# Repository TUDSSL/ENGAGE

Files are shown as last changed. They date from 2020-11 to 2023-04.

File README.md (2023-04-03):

# Battery-Free Game Boy

This is the official public repository for ENGAGE: the battery-free gaming console.
    
## Project Overview

### Rationale

Battery-free devices can [make phone calls](https://dl.acm.org/doi/abs/10.1145/3090090), [facilitate machine learning](https://dl.acm.org/doi/10.1145/3411808), or even [track eyes](https://doi.org/10.1145/3241539.3241578), but immersive interactive experience without batteries has not been explored so far. In this project we focus on this ignored part of the battery-free device ecosystem. We explore how reactive and user-centric applications, _mobile gaming_ in particular, can also be battery-free.	

### The Basic Problem of Gaming without Batteries: Power Failures 

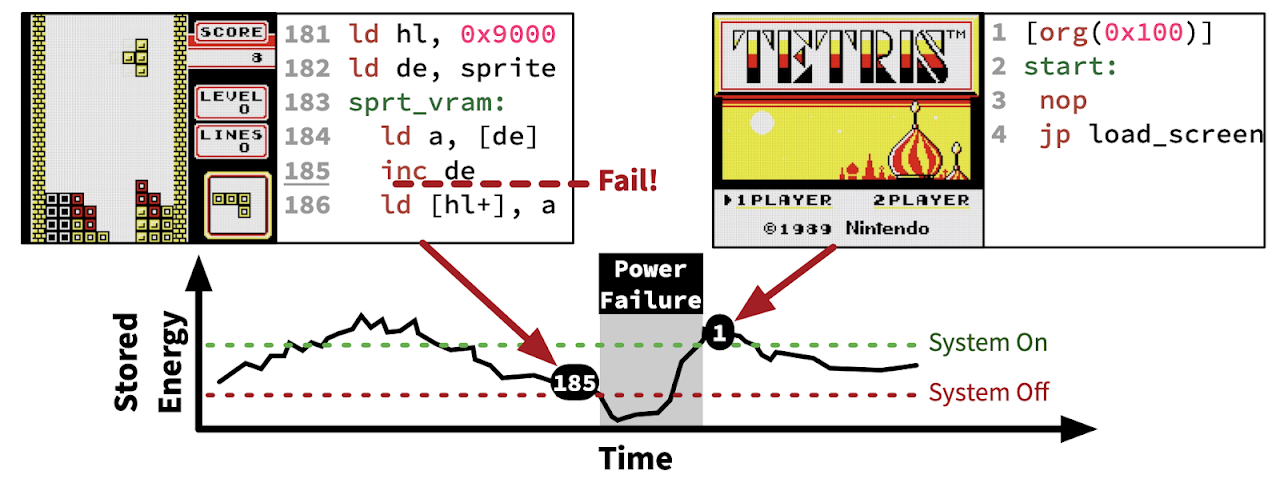
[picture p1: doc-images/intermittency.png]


Powering small embedded computer only with energy harvesting would cause frequent power failures, resulting in a constant restart of a long-running application. Let us look at the above figure which symbolically represents an execution of a [Tetris](https://en.wikipedia.org/wiki/Tetris) game on a battery-free platform powered by harvested (fluctuating) energy. Without any protection against power failures the game would play until energy is lost (i.e. at line 185) and then would restart from the loading screen. [Intermittent computing techniques](https://drops.dagstuhl.de/opus/volltexte/2017/7131/pdf/LIPIcs-SNAPL-2017-8.pdf) would protect from this unwanted behaviour: after a power failure, line 186 would be executed proceeding from the exact system state as before the power failure. This way a game state will resume at the exact frame where the play ended due to power failure (in other words, [tetromino](https://en.wikipedia.org/wiki/Tetromino) will be in the same place when the game resumes).

### System Design: Game Boy Emulation and System State Checkpointing

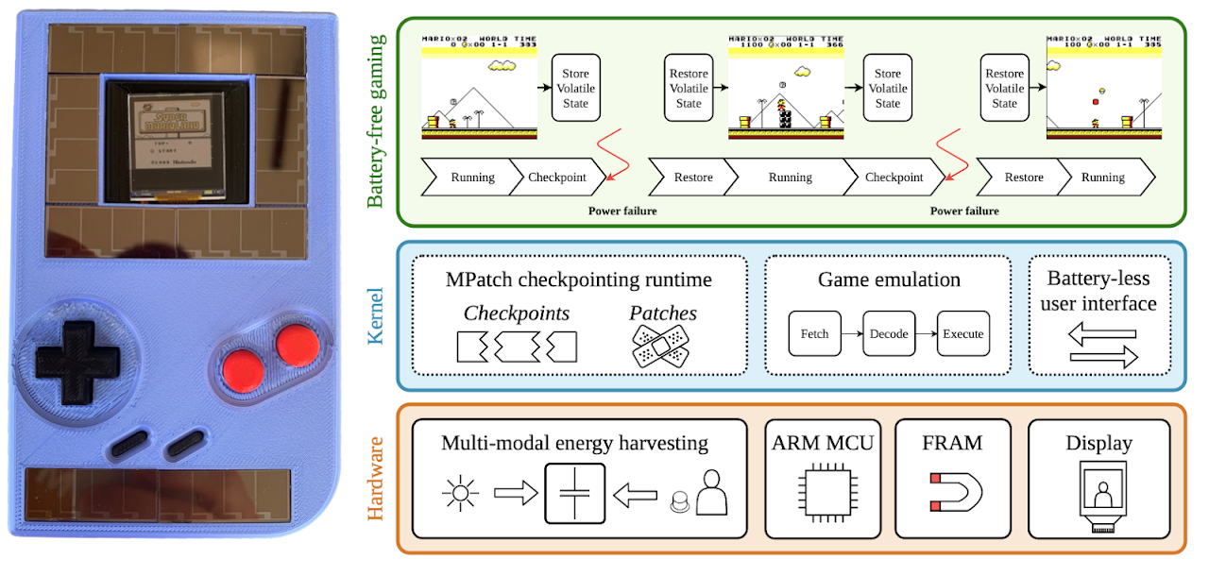
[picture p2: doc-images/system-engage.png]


We designed a Nintendo Game Boy emulator, which we call _Energy Aware Gaming (ENGAGE)_ platform, as a proof of concept that interactive systems powered by only by (intermittently-available) energy harvesting is possible. ENGAGE is build around four key components (see also figure above):

1. **Game emulation:** Use processor emulation to play (Game Boy) retro games to resemble classic [Game Boy](https://en.wikipedia.org/wiki/Game_Boy) platform feel;
1. **Kernel:** Efficiently checkpoint minimal game state to the dedicated non-volatile memory to protect from a restart after a power failure, enabling continuous game play;
1. **Energy:** Power battery-free gaming console from gaming actions (button presses) and from ambient solar energy and store this energy in a small capacitor;
1. **Hardware:** Exploit leading (but off-the-shelf and accessible to everyone) [low-power 32-bit ARM Cortex M4 microcontroller](https://ambiq.com/apollo3-blue/) and [external FRAM](https://www.fujitsu.com/global/documents/products/devices/semiconductor/fram/lineup/MB85RS4MT-DS501-00053-1v0-E.pdf) to support checkpointing system.

### Hardware

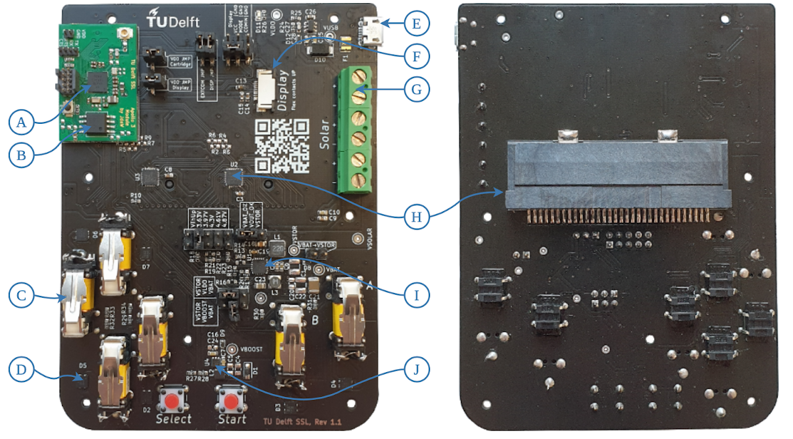
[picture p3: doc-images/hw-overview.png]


ENGAGE internal PCB is depicted on the above figure (left-hand side: front, right-hand side: back) with the main components (A) [Ambiq Apollo3 Blue ARM Cortex-M4 MCU](https://ambiq.com/apollo3-blue/), (B) [Fujitsu MB85RS4MT 512 KB FRAM](https://www.fujitsu.com/global/documents/products/devices/semiconductor/fram/lineup/MB85RS4MT-DS501-00053-1v0-E.pdf), (C) [ZF AFIG-0007 energy harvesting switch](https://nl.mouser.com/datasheet/2/833/Energy_Harvesting_Generator_US-1075748.pdf), (D) [Semiconductor Components Industries NSR1030QMUTWG low forward voltage diode bridge](https://www.onsemi.com/pub/Collateral/NSR1030QMU-D.PDF), (E) micro USB debugging port, (F) display connector, (G) solar panels connector, (H) cartridge interface, (I) [Texas Instruments BQ25570 harvester/power manager](https://www.ti.com/lit/ds/symlink/bq25570.pdf), and (J) [Texas Instruments TPS61099 boost converter](https://www.ti.com/lit/ds/symlink/tps61099.pdf).

The specific internals of ENGAGE are as follows.

**Microcontroller:** ENGAGE is based on [ARM MCU architecture](https://en.wikipedia.org/wiki/ARM_architecture), a departure from [Texas Instruments MSP430 FRAM series](https://www.ti.com/lit/an/slaa498b/slaa498b.pdf) microcontrollers typically used in [intermittent computing systems](https://drops.dagstuhl.de/opus/volltexte/2017/7131/pdf/LIPIcs-SNAPL-2017-8.pdf). Specifically, we have used [Ambiq Apollo3 Blue ARM Cortex-M4](https://ambiq.com/apollo3-blue/) (operating at a clock frequency of 96 MHz) chosen for its best-in-class energy efficiency. Apollo3 MCU (marked as (A) in the above figure) runs the Game Boy emulator and [checkpointing software](https://github.com/TUDSSL/ENGAGE/tree/master/software).

**Memory:** A fast, byte-addressable, non-volatile memory is crucial to enable saving and restoring ENGAGE state (in other words, game state) in spite of power failures. To enable this, we equipped ENGAGE with an external dedicated FRAM IC: [Fujitsu MB85RS4MT 512 KB FRAM](https://www.fujitsu.com/global/documents/products/devices/semiconductor/fram/lineup/MB85RS4MT-DS501-00053-1v0-E.pdf), marked as (B) in the above figure, connected through SPI to the MCU providing a fast (enough) and durable method of non-volatile storage for checkpoints.

**Energy Harvesting:** We extract energy from two sources: (i) button presses, using six mechanical off-the-shelf [ZF AFIG-0007 energy harvesting switches](https://nl.mouser.com/datasheet/2/833/Energy_Harvesting_Generator_US-1075748.pdf) - four switches at the D-pad and one switch per "A" and "B" button (see (C) in the above figure), and (ii) a set of [Panasonic AM-1417CA amorphous silicon solar cells](https://www.panasonic-electric-works.com/cps/rde/xbcr/pew_eu_en/ca_amorton_solar_cells_en.pdf) attached to the front of the Game Boy chassis. Solar panels are managed by [Texas Instruments BQ25570 harvester/power manager](https://www.ti.com/lit/ds/symlink/bq25570.pdf). Harvested energy is stored in a 3.3 mF capacitor.

**Cartridges:** To be able to read Game Boy game cartridges, a cartridge connector is placed on the back of the ENGAGE platform PCB (marked as (H) in the above figure). The cartridge interfaces with the MCU using [Semtech SX1503 I/O expanders](https://www.mouser.com/datasheet/2/761/sx150x-1283306.pdf). This extender translates the 3V system voltage to 5V logic required by the cartridge.

**Display:** It was difficult to source a large display that had reasonable power requirements, a decent refresh rate, and minimal external driving circuitry. We quickly discarded the use of electronic ink displays because of its slow refresh rate and complex driving circuitry. Instead we use a 26.02 × 27.82 mm [Japan Display LPM013M126A LCD](https://www.j-display.com/product/pdf/Datasheet/4LPM013M126A_specification_Ver02.pdf). The display is is smaller than the original Game Boy screen (47 × 43 mm) but has a better resolution of 176 × 176 pixels compared to original 160 × 144 pixel matrix.

### Checkpointing

The core software component of ENGAGE is differential checkpointing library called _MPatch_ located in [software/libs/mpatch](https://github.com/TUDSSL/ENGAGE/blob/master/software/libs/mpatch) folder of this repository. Further description of MPatch is provided in a separate [document](https://github.com/TUDSSL/ENGAGE/blob/master/software/libs/mpatch/README.md).

## Getting Started

This repository contains everything required to build your own Battery-Free Game Boy. Below we describe how to build your own ENGAGE hardware and software.

### Building the Hardware

Hardware-related sources are stored in the following folders.

 - [/enclosure](https://github.com/TUDSSL/ENGAGE/tree/master/enclosure): Complete set of [3D STL files](https://en.wikipedia.org/wiki/STL_%28file_format%29) of the complete ENGAGE enclosure (front, back, buttons, D-pad, LCD holder)
 - [/hardware/main-board](https://github.com/TUDSSL/ENGAGE/tree/master/hardware/main-board): Main ENGAGE board [KiCad](https://kicad.org/) files. Specifically, the folder contains `.gbr` Gerber output files for manufacturing, `.drl` drill file for manufacturing, schematics of the PCB in `.pdf` format, `.csv` file with bill of materials and the KiCad project files `.kicad_pcb`, `.pro` and `.sch`.
 - [/hardware/apollo-3-module](https://github.com/TUDSSL/ENGAGE/tree/master/hardware/apollo-3-module): As above, but for the de-attachable board with the MCU and FRAM (see above figure - component (A) and (B))
 
 Enclosure can be printed using your favorite 3D printer or you can send all [/enclosure](https://github.com/TUDSSL/ENGAGE/tree/master/enclosure) files to one of online-available 3D printing services. As for the PCBs, you can either assemble everything yourself or send all [/hardware](https://github.com/TUDSSL/ENGAGE/tree/master/hardware/) files to many online-available PCB assembly companies for production. 

### Building the Software

Software-related sources are stored in the following folders.

- [/software/apps](https://github.com/TUDSSL/ENGAGE/tree/master/software/apps): Applications' source code folder containing three applications:
    - [emulator](https://github.com/TUDSSL/ENGAGE/tree/master/software/apps/emulator): main application of ENGAGE emulator, which can be also used to reproduce [results of the paper](#How-to-Cite-This-Work);
    - [checkpoint](https://github.com/TUDSSL/ENGAGE/tree/master/software/apps/checkpoint): application to test the performance of checkpointing mechanism;
    - [memtracker](https://github.com/TUDSSL/ENGAGE/tree/master/software/apps/memtracker): application to test the performance of memory use tracking mechanism;
- [/software/config](https://github.com/TUDSSL/ENGAGE/tree/master/software/config): Various configuration files.
- [/software/external](https://github.com/TUDSSL/ENGAGE/tree/master/software/external): External dependencies to the project, such as MCU SDK.
- [/software/libs](https://github.com/TUDSSL/ENGAGE/tree/master/software/libs): Set of core libraries handling I/O (that is [console buttons](https://github.com/TUDSSL/ENGAGE/tree/master/software/libs/buttons), [game cartridge](https://github.com/TUDSSL/ENGAGE/tree/master/software/libs/cartridge), [console display](https://github.com/TUDSSL/ENGAGE/tree/master/software/libs/display), [Game Boy emulator](https://github.com/TUDSSL/ENGAGE/tree/master/software/libs/emulator), [FRAM access](https://github.com/TUDSSL/ENGAGE/tree/master/software/libs/fram)) and checkpointing (that is [just-in-time checkpoint](https://github.com/TUDSSL/ENGAGE/tree/master/software/libs/jit), [memory state tracker](https://github.com/TUDSSL/ENGAGE/tree/master/software/libs/memtracker), and [MPatch checkpointing](https://github.com/TUDSSL/ENGAGE/tree/master/software/libs/mpatch)).
- [/software/platforms](https://github.com/TUDSSL/ENGAGE/tree/master/software/platforms): GPIO pin mappings.
- [/software/scripts](https://github.com/TUDSSL/ENGAGE/tree/master/software/scripts): Scripts pertaining to the build process.

#### Note on the Game Boy Emulator

We do not provide the copy of the Game Boy emulator in this repository. Our build system (using [/software/scripts](https://github.com/TUDSSL/ENGAGE/tree/master/software/scripts)) automatically downloads and patches (applying optimizations and improvements) an external, not written by us, Game Boy emulator. Specifically, we have used [Game Boy emulator](https://mikrocontroller.bplaced.net/wordpress/?page_id=1290) for [STM32F746 Discovery board](https://www.st.com/en/evaluation-tools/32f746gdiscovery.html) written by [Uwe Becker](https://mikrocontroller.bplaced.net/wordpress/?page_id=8).

#### Build Process

After cloning this repository to your local computer the following instructions can be used to generate the ENGAGE binaries. From the project directory execute the following.

```bash
$ cd software/build
$ cmake ..
$ make install

```

Then using your favorite debugger (we have used one of [SEGGER J-Link debug probes](https://www.segger.com/products/debug-probes/j-link/models/model-overview/) for this project) the ENGAGE binaries (stored in the [/software/bin](https://github.com/TUDSSL/ENGAGE/tree/master/software/bin) folder) can be uploaded to the MCU using a debugger whilst powering the platform using USB. The main binary is called `emulator` whilst the others provide a means to reproduce the results obtained in the [paper](#How-to-Cite-This-Work). After this step a [game cartridge can be loaded](#Load-Game-Cartridge).

#### Last Tested Software Versions

This software was build successfully using the following software versions.

- [CMake](https://cmake.org/download/) version 3.18.4
- [arm-none-eabi-gcc](https://gcc.gnu.org/) version 10.2.0
- [arm-none-eabi-newlib](https://www.sourceware.org/newlib/) version 3.3.0
- [arm-none-eabi-binutils](https://www.gnu.org/software/binutils/) version 2.35

## How to Operate ENGAGE

There are two important operations when using ENGAGE that are not related to normal gaming: **loading game cartridge** and **system reset**, both described below.

### Load Game Cartridge

After programming the [emulator binary](https://github.com/TUDSSL/ENGAGE/tree/master/software/bin) to ENGAGE, a Game Boy cartridge with your favorite game needs to be loaded to ENGAGE. To load a cartridge, first put the physical cartridge in the cartridge slot (at the back of ENGAGE) and then hold down **Start** and **A** buttons on ENGAGE while powering ENGAGE through the USB port. You can let go **Start** and **A** buttons after a few seconds. When loading of the cartridge has completed the game will start. Note that there is currently [no progress indication](https://github.com/TUDSSL/ENGAGE/issues/4) of this operation on the screen of ENGAGE. Remember that the process can take five minutes (or more) for large cartridges! After a cartridge has been loaded it can be removed from the device.

### System Reset

Due to the unique nature of ENGAGE's state resuming after power failure, resetting ENGAGE requires a unique key combination (unlike the original Game Boy that you could turn off and on again easily). This reset is performed by holding **Start** and **Select** buttons while powering ENGAGE through an USB port. Please note that this reset operation does *not* require you to reload the game cartridge.

## Frequently Asked Questions

- **When the energy source is changed from solar to button-mashing, how long is ENGAGE temporarily off?**

We actually harvest from both energy sources at the same time! We developed a circuit that manages this internally. However, this still means that the user will experience interruptions of play, that can vary between sub-second (in extreme well outdoor light conditions) to many seconds (on a gloomy day, indoors). While the button presses generate extra energy to sustain game play, most of the energy is still generated by solar panels. More discussion on this can be found in our [research paper](#How-to-Cite-This-Work). 

- **How do the buttons generate power?**

The buttons generate power by moving a small but powerful magnet inside a tightly wound wire coil. The change in the magnetic field generates power. When you press the button (and when you release) it moves the magnet through the coil, this energy is then siphoned into a capacitor for immediate use by the ENGAGE hardware to support all activities. Because of advances in manufacturing over the past decade the magnet and coil are so small that they can fit inside a button that is acceptable to a user.

- **Why is the screen so small?**

Yes, the screen is smaller that in the original Game Boy (which is a [source of complaints](https://www.reddit.com/r/gadgets/comments/in3aco/batteryfree_game_boy_runs_off_of_solar_and/) of many internauts), but the one we [used in the initial ENGAGE design](https://www.j-display.com/product/pdf/Datasheet/4LPM013M126A_specification_Ver02.pdf) the best one we could find in terms of resolution and energy consumption. If you have a better screen to suggest, then make a new [project issue](#How-to-Contribute-to-this-Project) and send us a [pull request](#How-to-Contribute-to-this-Project).

- **Can ENGAGE play sound?**

Unfortunately not. Sound generation costs extra energy and as we operate on a very thin energy budget we had to make choices which features of original Game Boy had to be excluded from ENGAGE.

- **Can I buy one?**

Unfortunately not. But you can build one! All hardware and software of ENGAGE, together with the process of how to make it run is simply in _this repository_. Please remember that ENGAGE **was not (and is not meant to be) a product we can sell**. This is a research project and a concept demonstration.

## How to Contribute to this Project

We look forward to your contributions, improvements, additions and changes. Please follow the standard [GitHub flow](https://docs.github.com/en/free-pro-team@latest/github/collaborating-with-issues-and-pull-requests/github-flow) for code contributions. In macro terms this means the following.

1. [Fork the `master` branch](https://docs.github.com/en/free-pro-team@latest/github/getting-started-with-github/fork-a-repo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)  of this repository; make sure that your fork will be [up to date](https://docs.github.com/en/free-pro-team@latest/github/getting-started-with-github/fork-a-repo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) with the latest `master` branch.
1. Create an issue [here](https://github.com/TUDSSL/ENGAGE/issues) with a new feature or a bug report.
1. Perform changes on your local branch and [push them to your forked clone](https://docs.github.com/en/free-pro-team@latest/github/collaborating-with-issues-and-pull-requests/merging-an-upstream-repository-into-your-fork).
1. Create a [pull request](https://docs.github.com/en/free-pro-team@latest/github/collaborating-with-issues-and-pull-requests/creating-a-pull-request) referencing the issue it covers and wait for our response.

### List of Known Issues

List of all known issues is listed in the [Issues](https://github.com/TUDSSL/ENGAGE/issues) list of this project. If you found a bug or you would like to enhance ENGAGE: [please contribute](#How-to-Contribute-to-this-Project)! We look forward to your additions. Let ENGAGE grow and become a better and **more sustainable** gaming experience.

## How to Cite This Work

The results of this project have been published in a peer-reviewed academic publication (from which all technical figures in this file originate). Details of the publication are as follows.

* **Authors and the project team:** [Jasper de Winkel](https://jasperdewinkel.com/), [Vito Kortbeek](https://www.vitokortbeek.com/), [Josiah Hester](https://josiahhester.com/), [Przemysław Pawełczak](http://www.pawelczak.net/)
* **Publication title:** _Battery-Free Game Boy_
* **Pulication venue:** [Proceedings of the ACM on Interactive, Mobile, Wearable and Ubiquitous Technologies, Volume 4, Issue 3, September 2020](https://dl.acm.org/toc/imwut/2020/4/3) and [Proceedings of ACM UbiComp 2020](https://ubicomp.org/ubicomp2020/)
* **Link to publication:** https://doi.org/10.1145/3411839 (Open Access)
* **Link to ACM UbiComp 2020 conference presentation video:** https://www.youtube.com/watch?v=XxjrTHBFBSM

To cite this publication please use the following BiBTeX entry.

```
@article{dewinkel:imwut:2020:gameboy,
  title = {Battery-Free Game Boy},
  author = {Jasper {de Winkel} and Vito {Kortbeek} and Josiah {Hester} and Przemys{\l}aw {Pawe{\l}czak}},
  journal = {Proc. ACM Interact. Mob. Wearable Ubiquitous Technol.},
  volume = {4},
  number = {3},
  pages = {111:1--111:34},
  year = {2020},
  publisher = {ACM}
}
```

## Related Websites

* **Project source code:** https://github.com/tudssl/engage (this repository)
* **Project announcement website:** https://www.freethegameboy.info

## The Press

The project has been covered extensively by international media. Here is the list of example posts and articles (as of October 30, 2020).

[CNET](https://www.cnet.com/features/the-first-battery-free-game-boy-wants-to-power-a-gaming-revolution/), [The Wall Street Journal](https://www.wsj.com/articles/battery-free-energy-harvesting-perpetual-machines-the-weird-future-of-computing-11601697600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), [Mashable](https://mashable.com/video/battery-free-gameboy/), [Hackaday](https://hackaday.com/2020/09/11/game-boy-plays-forever/), [The Verge](https://www.theverge.com/tldr/2020/9/4/21422605/engage-battery-free-game-boy-button-mashing-solar-panels-research-environmental-sustainability), [Gizmodo](https://earther.gizmodo.com/this-battery-free-game-boy-is-the-first-step-toward-ens-1844953062), [Engadget](https://www.engadget.com/engage-game-boy-211023869.html), [PCMag](https://www.pcmag.com/news/solar-powered-game-boy-provides-infinite-play), [The Register](https://www.theregister.com/2020/09/04/battery_free_gameboy/), [Tech Times](https://www.techtimes.com/articles/252268/20200903/game-boy-gaming-console-battery-free-play-want-without-recharging.htm), [Nintendo Life](https://www.nintendolife.com/news/2020/09/this_battery-free_game_boy_could_be_the_future_of_portable_tech), [Daily Mail](https://www.dailymail.co.uk/sciencetech/article-8695791/Battery-free-Game-Boy-charged-MILLIONS-times-sun-pressing-buttons.html), [The Independent](https://www.independent.co.uk/life-style/gadgets-and-tech/news/game-boy-battery-free-technology-renewable-power-a9705256.html), [r/gadgets](https://www.reddit.com/r/gadgets/comments/in3aco/batteryfree_game_boy_runs_off_of_solar_and/)

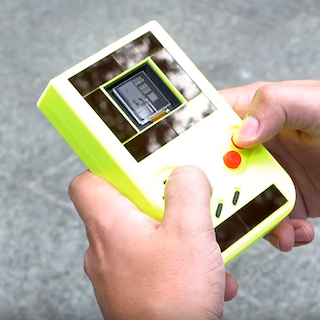
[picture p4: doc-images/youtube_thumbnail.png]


## Acknowledgments

This research project was supported by [Netherlands Organisation for Scientific Research](https://www.nwo.nl/en), partly funded by the [Dutch Ministry of Economic Affairs and Climate Policy](https://www.government.nl/ministries/ministry-of-economic-affairs-and-climate-policy), through [TTW Perspective program ZERO (P15-06)](https://www.nwo.nl/en/researchprogrammes/perspectief/previous-awards/zero-towards-energy-autonomous-systems-iot) within Project P1 and P4, and by the [National Science Foundation](https://www.nsf.org/) through grants [CNS-1850496](https://www.nsf.gov/awardsearch/showAward?AWD_ID=1850496) and [CNS-2032408](https://www.nsf.gov/awardsearch/showAward?AWD_ID=2032408). Any opinions, findings, and conclusions or recommendations expressed in this material are those of the author(s) and do not necessarily reflect the views of the National Science Foundation.

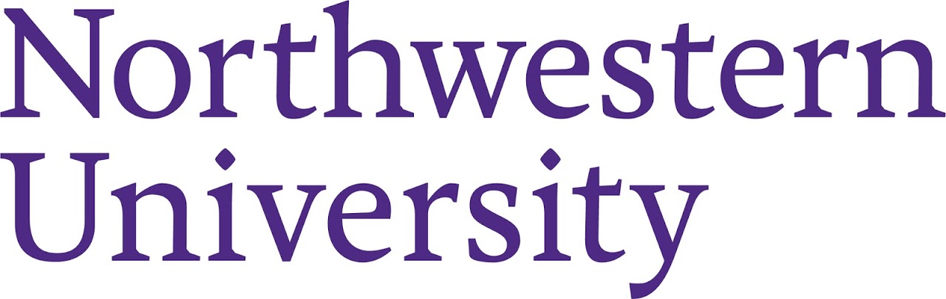
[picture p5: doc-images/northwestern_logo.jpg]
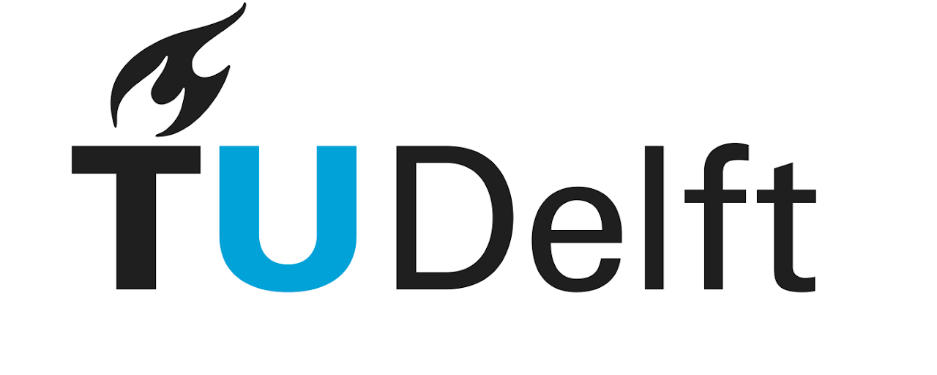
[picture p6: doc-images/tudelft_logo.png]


## Copyright

Copyright (C) 2020 TU Delft Embedded and Networked Systems Group/Sustainable Systems Laboratory.

MIT License or otherwise specified. See [license](https://github.com/TUDSSL/ENGAGE/blob/master/LICENSE) file for details.

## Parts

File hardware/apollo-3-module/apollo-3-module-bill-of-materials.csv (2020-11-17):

Item | Qty | Reference(s) | Value | Datasheet | Partnum
1 | 5 | C1, C5, C10, C11, C15 | 1uF | ~ | GRM155C81A105KA12D
2 | 5 | C2, C4, C13, C17, C18 | DNP | ~
3 | 1 | C3 | 470nF | ~ | GRT155R61C474KE01D
4 | 1 | C6 | 47nF | ~ | GRM155R71E473KA88D
5 | 4 | C7, C8, C9, C16 | 2.2uF | ~ | GRM155R61C225KE11D
6 | 1 | C12 | 0.5pF | ~ | GRM1885C1HR50BA01D
7 | 1 | C14 | 4.7uF | ~ | CL05A475KP5NRNC
8 | 1 | C19 | 1uF | ~ | TMK107B7105KA-T
9 | 2 | H1, H2 | eC_Registration | https://www.eurocircuits.com/ec-registration-system/
10 | 2 | J1, J2 | 51338-0374 | https://www.molex.com/webdocs/datasheets/pdf/en-us/0513380374_PCB_RECEPTACLES.pdf | 51338-0374
11 | 1 | J3 | Conn_01x04 | ~ | GRPB041VWVN-RC
12 | 1 | J4 | SWD_10 | http://infocenter.arm.com/help/topic/com.arm.doc.ddi0314h/DDI0314H_coresight_components_trm.pdf | FTSH-105-01-F-D-K
13 | 1 | J5 | Conn_Coaxial | ~ | U.FL-R-SMT-1
14 | 1 | J6 | Conn_01x02 | ~ | GRPB021VWVN-RC
15 | 1 | L1 | 2.2uH | ~ | DFE201610E-2R2M=P2
16 | 1 | L2 | 1uH | ~ | DFE18SAN1R0MG0L
17 | 1 | L3 | 2.7nH | ~ | LQG15HS2N7S02D
18 | 1 | L4 | 2nH | ~ | LQG15HS2N0S02D
19 | 1 | R1 | 0 | ~ | ERJ-3GEY0R00V
20 | 4 | R2, R6, R7, R8 | DNP | ~
21 | 1 | R3 | 0 | ~ | ERJ-2GE0R00X
22 | 2 | R4, R5 | 10k | ~ | ERJ-3GEYJ103V
23 | 1 | SW1 | B3U-1000P | ~ | B3U-1000P
24 | 1 | U1 | APOLLO3 | https://www.ambiqmicro.com/static/mcu/files/Apollo3_Blue_MCU_Data_Sheet_v0_10_0.pdf | AMA3B1KK-KBR-B0
25 | 1 | U2 | MB85RS4MT | https://www.fujitsu.com/global/documents/products/devices/semiconductor/fram/lineup/MB85RS4MT-DS501-00053-1v0-E.pdf | MB85RS4MT
26 | 1 | Y1 | ECS-320-8-47-JTN | https://nl.mouser.com/datasheet/2/122/ECX_1247-220263.pdf | ECS-320-8-47-JTN
27 | 1 | Y2 | ABS06W-32.678kHz-D-2 | https://abracon.com/Resonators/ABS06W.pdf | ABS06W-32.768kHz-D-2

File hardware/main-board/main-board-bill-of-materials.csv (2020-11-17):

Item | Qty | Reference(s) | Value | Datasheet | MPN
1 | 2 | C1, C22 | DNP | ~
2 | 3 | C2, C19, C26 | 10nF | ~ | 06035C103KAT2A
3 | 6 | C3, C8, C9, C13, C17, C29 | 100nF | ~ | GCM188R71H104KA57D
4 | 3 | C4, C5, C20 | DNP | ~
5 | 1 | C6 | 4.7uF | ~ | LMK107BJ475KA-T
6 | 5 | C7, C10, C24, C25, C28 | 10uF | ~ | GRM188R61A106KE69D
7 | 4 | C11, C12, C14, C15 | 1uF | ~ | CL10B105KP8NNNC
8 | 1 | C16 | DNP | ~
9 | 1 | C18 | 4.7uF | ~ | CL21A475KOFNNNE
10 | 1 | C21 | 100uF | ~ | LMK325BJ107MM-T
11 | 1 | C23 | 22uF | ~ | CL21A226KPCLRNC
12 | 1 | C27 | 15pF | ~ | CC0603JRNPO9BN150
13 | 1 | D1 | SZMM3Z5V1ST1G | https://diotec.com/tl_files/diotec/files/pdf/datasheets/mm3z2v4.pdf | SZMM3Z5V1ST1G
14 | 6 | D2, D3, D4, D5, D6, D7 | NSR1030QMUTWG | https://www.onsemi.com/pub/Collateral/NSR1030QMU-D.PDF | NSR1030QMUTWG
15 | 3 | D8, D9, D12 | BAS40-02V-V-G-08 | ~ | BAS40-02V-V-G-08
16 | 1 | D10 | 3SMAJ5919B-TP | ~ | 3SMAJ5919B-TP
17 | 1 | D11 | LED | ~ | LB Q39G-L2OO-35-1
18 | 1 | F1 | MF-USMF010 | ~ | MF-USMF010
19 | 7 | H1, H2, H3, H4, H5, H6, H7 | MountingHole | ~
20 | 2 | H8, H9 | eC_Registration | https://www.eurocircuits.com/ec-registration-system/
21 | 2 | J1, J2 | Conn_01x02 | ~ | GBC02SABN-M30
22 | 1 | J3 | 52745-1097 | ~ | 52745-1097 | LCD: LPM013M126A or LPM013M126C
23 | 1 | J9 | GB_CART_CON | https://aliexpress.com/item/4000290191316.html
24 | 1 | J12 | Conn_02x02_Odd_Even | ~ | M20-8760242
25 | 3 | J14, J19, J20 | Conn_01x03 | ~ | M20-9990345
26 | 1 | J15 | Conn_02x03_Odd_Even | ~ | M20-8760346
27 | 1 | J17 | Conn_01x02 | ~ | M20-9990246
28 | 1 | J18 | Conn_02x05_Odd_Even | ~ | M20-9720545
29 | 1 | J21 | USB_B_Micro | https://www.molex.com/pdm_docs/sd/1050170001_sd.pdf | 1050170001
30 | 3 | J22, J23, J24 | Screw_Terminal_01x02 | ~ | 282837-2
31 | 1 | L1 | 744031220 | ~ | 744031220
32 | 1 | L2 | LQH2HPN2R2MJRL | ~ | LQH2HPN2R2MJRL
33 | 1 | L3 | 744029100 | ~ | 744029100
34 | 2 | R1, R19 | 2M | ~ | RC0603FR-072ML
35 | 8 | R2, R3, R4, R5, R6, R7, R8, R9 | DNP | ~
36 | 11 | R10, R11, R18, R27, R28, R29, R30, R31, R32, R33, R34 | 1M | ~ | RC0603FR-071ML
37 | 1 | R13 | 8.2M | ~ | CRCW06038M20FKEA
38 | 2 | R14, R23 | 4.7M | ~ | RC0603FR-074M7L
39 | 1 | R15 | 7.5M | ~ | CRCW06037M50FKEA
40 | 1 | R16 | 5.1M | ~ | CRCW06035M10FKEA
41 | 1 | R17 | 3.6M | ~ | CRCW06033M60FKEA
42 | 1 | R20 | 6.2M | ~ | CRCW06036M20FKEA
43 | 1 | R21 | 3M | ~ | CRCW06033M00FKEA
44 | 1 | R22 | 3.9M | ~ | CRCW06033M90FKEA
45 | 1 | R24 | 82k | ~ | RC0603FR-0782KL
46 | 1 | R25 | 30.1k | ~ | RC0603FR-0730K1L
47 | 1 | R26 | 560 | ~ | RC0603FR-07560RL
48 | 1 | S1 | TUD_SSL_QR
49 | 1 | S2 | TUD_LOGO
50 | 2 | SW1, SW2 | SW_Push | ~ | 1825910-7
51 | 6 | SW4, SW5, SW6, SW7, SW8, SW9 | EH_SWITCH | ~ | AFIG-0007 and RT1105AF160Q
52 | 1 | U1 | BQ25570 | http://www.ti.com/lit/ds/symlink/bq25570.pdf | BQ25570RGR
53 | 2 | U2, U3 | SX1503 | https://nl.mouser.com/datasheet/2/761/sx150x-1283306.pdf | SX1503
54 | 1 | U4 | TPS610995DRV | http://www.ti.com/lit/ds/symlink/tps61099.pdf | TPS610995DRV
55 | 1 | U5 | Apollo-3-module | https://www.ambiqmicro.com/static/mcu/files/Apollo3_Blue_MCU_Data_Sheet_v0_10_0.pdf | 2 x 55909-0374
56 | 1 | U7 | TPS79301-EP | http://www.ti.com/lit/ds/symlink/tps79333-ep.pdf | TPS79301DBV
57 | 6 | SOLAR | AM-1417CA | https://www.panasonic-electric-works.com/cps/rde/xbcr/pew_eu_en/ca_amorton_solar_cells_en.pdf | AM-1417CA
57 | 1 | DISPLAY | LPM013M126A | https://www.j-display.com/product/pdf/Datasheet/4LPM013M126A_specification_Ver02.pdf | LPM013M126A

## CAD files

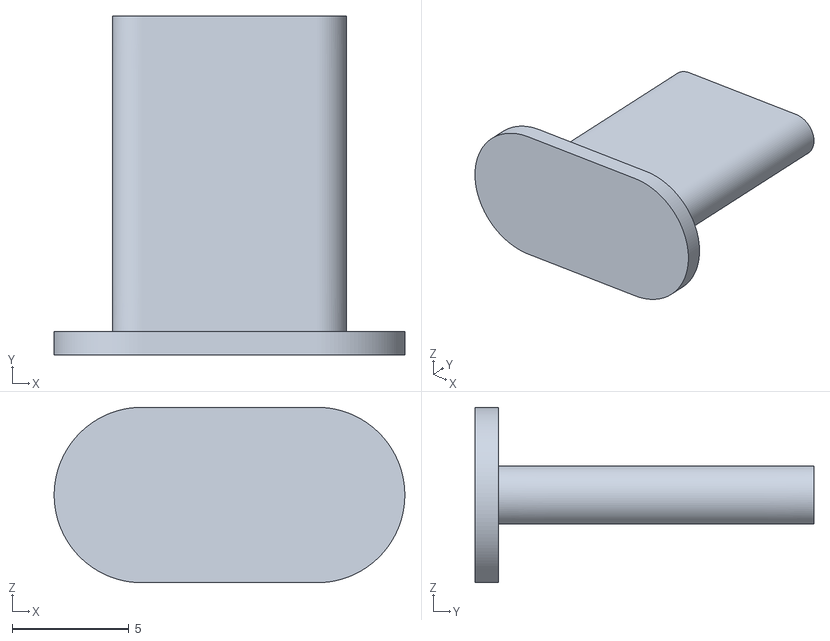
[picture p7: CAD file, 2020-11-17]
enclosure/ENGAGE-Small-Button.stl
15.0 x 14.5 x 7.50

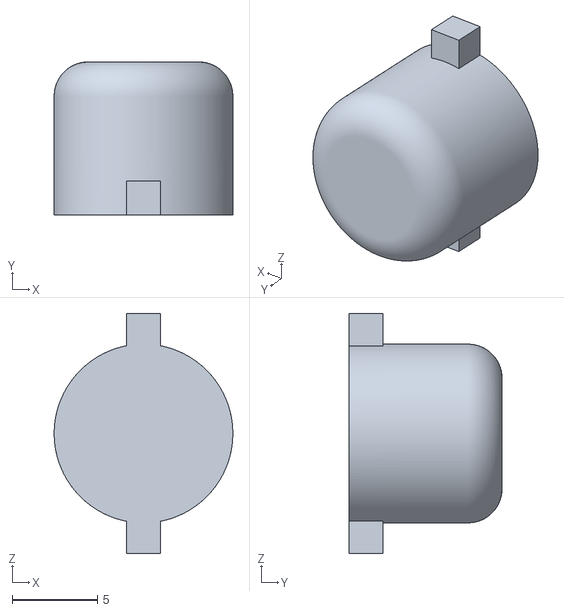
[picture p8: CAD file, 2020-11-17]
enclosure/ENGAGE-Button.stl
10.5 x 9.00 x 14.1

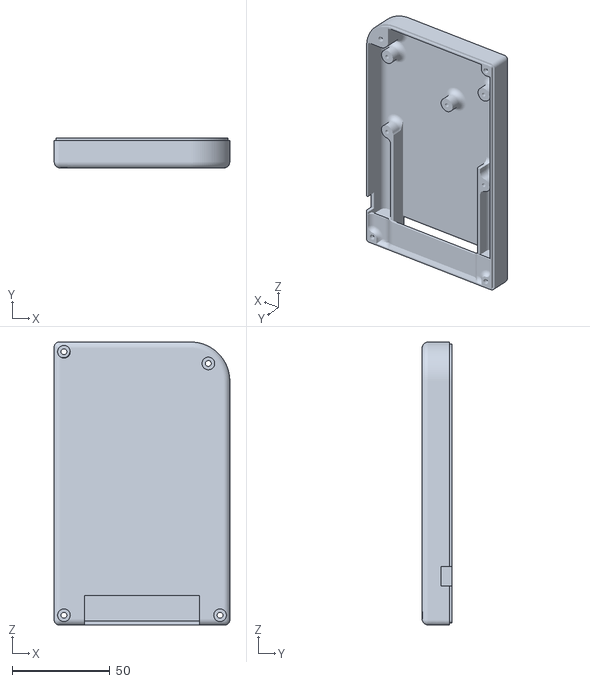
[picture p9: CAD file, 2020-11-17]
enclosure/ENGAGE-Bottom.stl
90.0 x 15.4 x 145.0

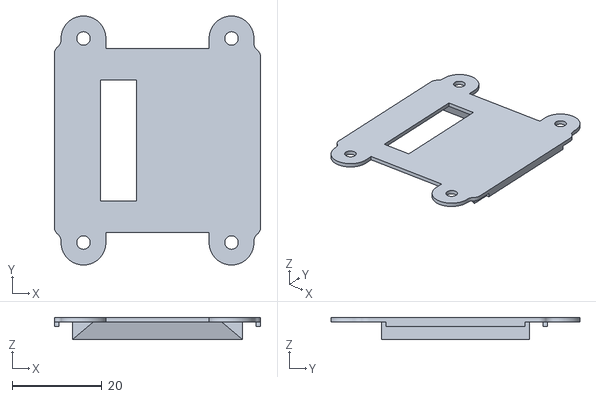
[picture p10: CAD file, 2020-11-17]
enclosure/ENGAGE-LCD-Holder.stl
46.0 x 55.5 x 5.00

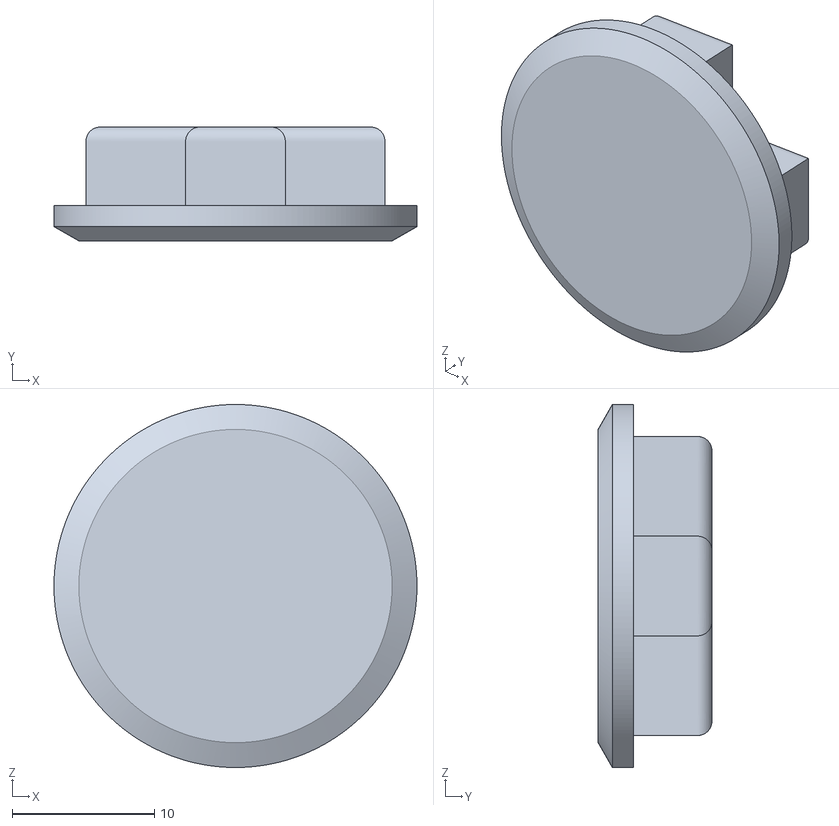
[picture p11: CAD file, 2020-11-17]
enclosure/ENGAGE-DPad.stl
25.5 x 8.00 x 25.5

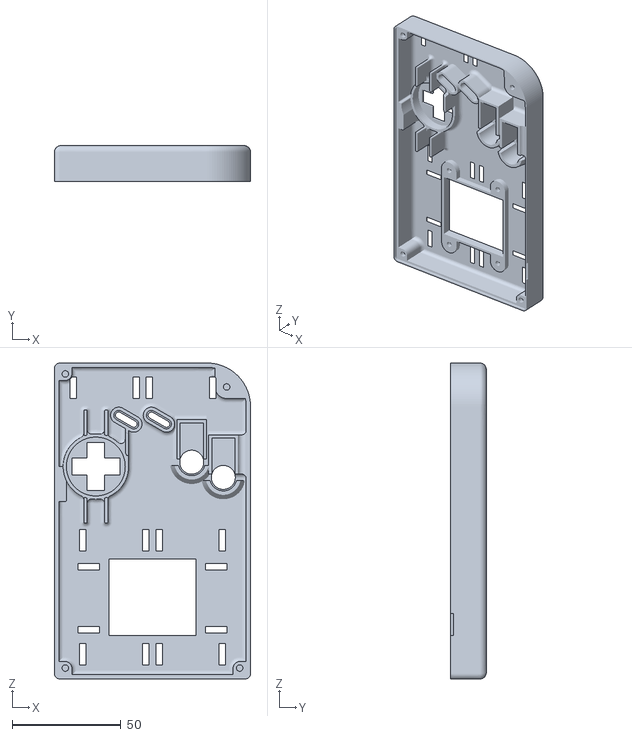
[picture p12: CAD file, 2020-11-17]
enclosure/ENGAGE-Top.stl
90.0 x 16.4 x 145.0

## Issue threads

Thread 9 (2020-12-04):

Few question about design

tuantdang, 2020-12-04:
Thank you for your awesome work! I'm really interested in this project!
I'm also building a battery-free device for my application that is related to your work, so I have some questions that need to be clarified:
1. Your design harvest energy from solar and button action, then store in a capacitor to power the device. As I know a capacitor looks like a battery but it stores less energy than a battery. What if you do not play the games and the capacitor is fully charged? Is it a waste of energy while the device is idle?
2. As far I know, the implementation of MPatch run-time is consuming power. I want to know the level of play game versus the level of running MPatch lib. If the cost of running this run-time lib is large, it could contribute to the frequent failure in power.
3. Could we use a bigger capacitor or multiple capacitors to store energy to avoid frequent power failure?

Thank you!
I'm looking forward to hearing your response!
Or you can drop me a message at: ttd9645@mavs.uta.edu
Best regards,
Tuan Dang

przemyslaw-pawelczak, 2020-12-04:
Dear @tuantdang thank you for your interest in this project. We're really interested to hear about your own battery-less device.

Here are our quick answers to your questions:

- __Regarding 1.__ Indeed, a capacitor (just like battery) has finite volume and cannot store infinite amount of energy. So from this perspective as you rightly point out we _waste_ the opportunity of storing more energy for the future.
- __Regarding 2.__ Yes, as you correctly observe, `MPatch` (as any other runtime) will introduce overhead (however in case of `MPatch` that memory overhead is small - each patch takes 29 B of memory, see [ __Patch Allocation__](https://dl.acm.org/doi/epdf/10.1145/3411839) section of the ENGAGE paper. But I guess your question implies that if `MPatch` would have almost zero overhead, the game play would significantly improve. The answer is "Yes"... however the biggest performance killer of all the software running in ENGAGE is the game emulator - running games natively would in our opinion improve game play much more than making `MPatch' more efficient
- __Regarding 3.__ Yes, both are possible. However, bigger capacitor results in longer startup time after every power failure. In my humble opinion capacitor bank would be an interesting solution to consider (which was already proposed by other research groups working in intermittently-powered systems).

Hope I was able to answer your questions. Feel free to send a follow-up questions!

tuantdang, 2020-12-07:
Dear @przemyslaw-pawelczak,
Thank you for your quick reply.

Another point that I concerned about is when to do the checkpoint.
When reading the paper, I think there are some ways to predict power failure before doing checkpoints.
 I tried to find it in the source code, but I could not.

Below is the code that I found. As source code: Checkpoint is done every 5 times after gameboy_single_step, whose source is not available in the repository, could you explain it?

=====================
void emulatorRun() {
  while (true) {
    gameboy_single_step();
#ifdef CHECKPOINT
    if (jit_checkpoint) {
      if (jitCheckpointcount == 0) {
        jitCheckpointcount = 5;
        checkpoint();
      } else {
        jitCheckpointcount--;
      }

      jit_checkpoint = 0;
    }
#endif
  }
}

iiKoe, 2020-12-07:
Hi @tuantdang

That piece of code ([software/libs/emulator/emulator.c](https://github.com/TUDSSL/ENGAGE/blob/8dc37dbfc83d2d49d5927515044ca350b20f0fdd/software/libs/emulator/emulator.c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)) performs a checkpoint (of the changed memory) **if** the `jit_checkpoint` variable is not zero for 5 emulation steps. This `jit_checkpoint` variable is set in an interrupt defined in [software/libs/jit/jit_checkpoint.c](https://github.com/TUDSSL/ENGAGE/blob/8dc37dbfc83d2d49d5927515044ca350b20f0fdd/software/libs/jit/jit_checkpoint.c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). This interrupt is an ADC interrupt that is connected to the voltage level of the buffer/storage capacitor.

I hope this clears thing up :)

tuantdang, 2020-12-08:
Dear @iiKoe,

As far I understand that when the interrupt on ADC (specifically, Window comparator voltage excursion interrupt) occurs the flag jit_checkpoint will be raised up. After 5 emulation steps with the raised flag, the checkpoint will be executed.

My question is how long is **gameboy_single_step()** 's execution time?
Have the Gamboy could missed some checkpoints because of 5 times execution of **gameboy_single_step**?

How about if checkpoint should be placed in the ADC interrupt service routine to response immmediately to power failure?

I think there are some reasons behind it.
I'm very happy if you share more about it.

P/S: I'm very interesting on this project and I'd like to learn more about it.
I'm sorry if these questions bother you guys. ^^

Thank you!

iiKoe, 2020-12-08:
No problem @tuantdang, we will be happy to answer your questions :smiley:

I don't know the exact time `gameboy_single_step()` takes to execute, and it will vary somewhat, I think, due to the graphics emulation (not 100% sure). But in any case, the execution time is very short in the grand scheme of things (it's one assembly instruction of the z80 + some graphics). Placing the checkpoint in the interrupt might lead to some hard to debug situations compared to placing it at the start of the emulation loop, and it will not lead to any real benefits.

The magic number `5` is empirically chosen. It limits the number of checkpoints so that the system can also emulate some Game Boy code between checkpoints if the system reaches the "low energy" state (i.e., `jit_checkpoint==1`). This is just a very simple way to space out the checkpoints. Because the variable `jitCheckpointcount` has the keyword `CHECKPOINT_EXCLUDE_BSS` before it, it will be set to zero at every boot, so after a boot, the first checkpoint will always execute immediately (no 5 wait steps).
As you might observe, if the system gets out of the low energy state without rebooting, the variable does not reset to zero, but this is an edge case and not worth optimizing for.

Closed 2020-12-08.

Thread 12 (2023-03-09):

Add third source of power, automatic winding of a mainspring, like found in automatic (self-winding) watches

NeccoNeko, 2023-03-09:
For example:

https://en.wikipedia.org/wiki/Automatic_watch

https://phys.org/news/2015-11-self-powered-e-watch-powered-wrist-movements.html

01010111, 2023-03-11:
I feel like you also have up to eight more sources if you count the fingers grasping the back of the console! My first thought was triggers similar to one of these:

https://www.firesupplydepot.com/dynamo-3-led-squeeze-flashlight.html

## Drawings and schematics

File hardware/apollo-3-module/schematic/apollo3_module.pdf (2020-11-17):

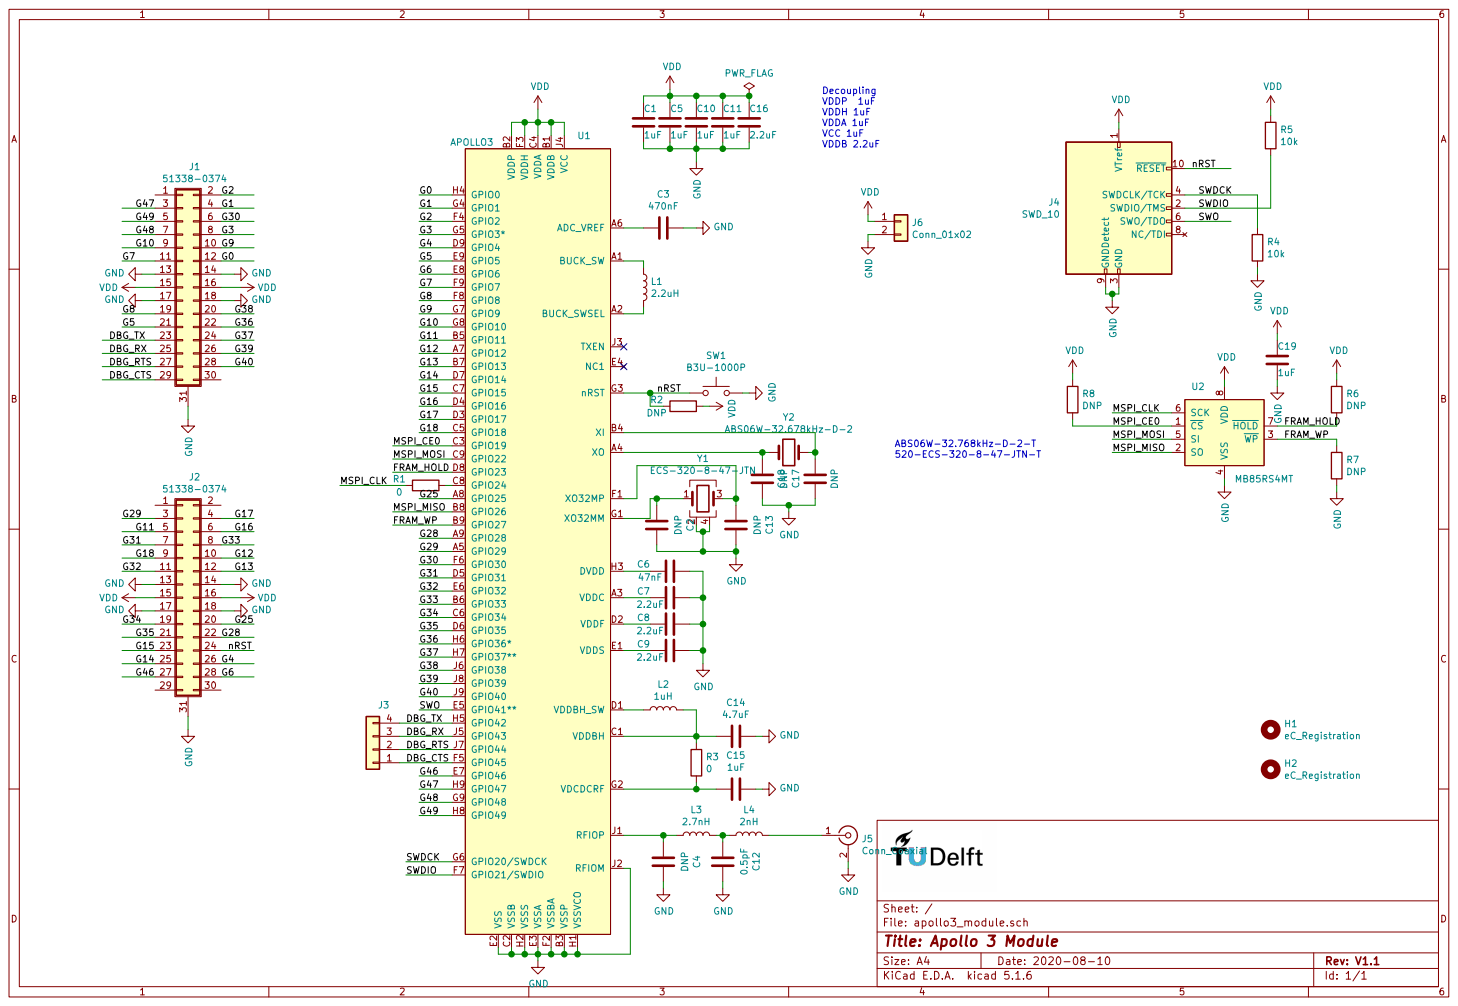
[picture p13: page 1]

4 Y1 ECS-320-8-47-JTN C18 DNP GND C12 0.5pF BUCK_SW A1 BUCK_SWSEL A2 VDDC A3 XO A4 GPIO29 A5 ADC_VREF A6 GPIO12 A7 GPIO25 A8 GPIO28 A9 VDDB B1 VDDP B2 VSSP B3 XI B4 GPIO11 B5 GPIO33 B6 GPIO13 B7 GPIO26 B8 GPIO27 B9 VDDBH C1 VSSB C2 GPIO19 C3 VDDA C4 GPIO18 C5 GPIO34 C6 GPIO15 C7 GPIO24 C8 GPIO22 C9 VDDBH_SW D1 VDDF D2 GPIO17 D3 GPIO16 D4 GPIO31 D5 GPIO35 D6 GPIO14 D7 GPIO23 D8 GPIO4 D9 VDDS E1 VSS E2 VSSA E3 NC1 E4 GPIO41** E5 GPIO32 E6 GPIO46 E7

3 SWDCLK/TCK 4 SWO/TDO 6 NC/TDI 8 GNDDetect 9

4 SI 5 SCK 6 HOLD VDD 7

Id: 1/1 Title: Apollo 3 Module

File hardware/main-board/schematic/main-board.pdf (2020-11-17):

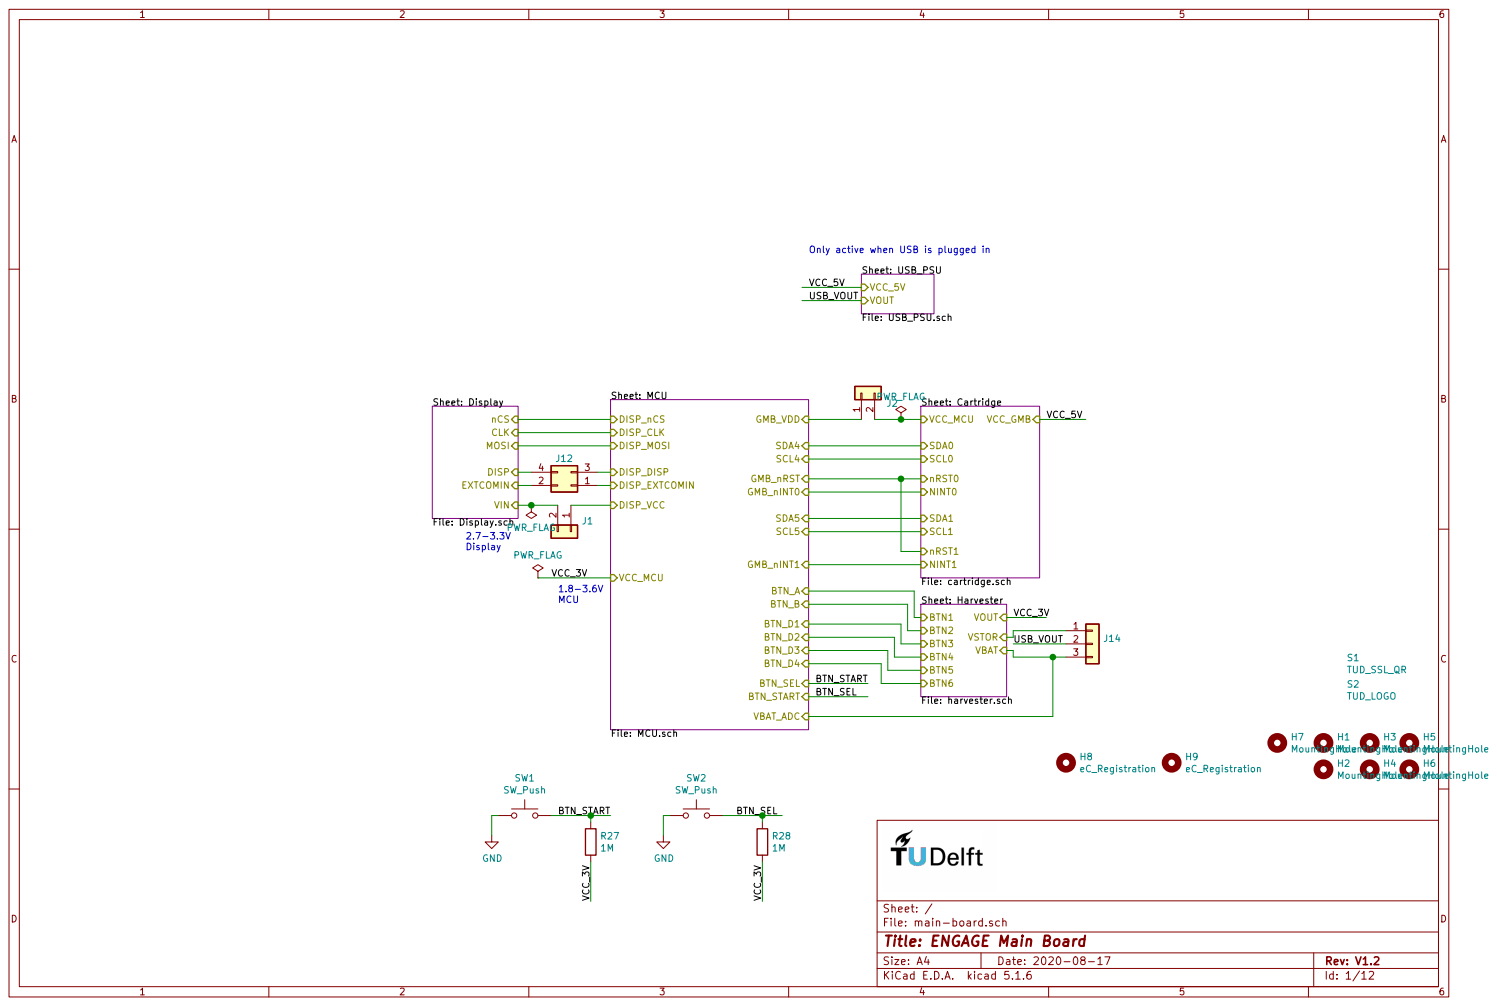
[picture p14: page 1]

CLK MOSI nCS DISP

File: Display.sch EXTCOMIN

Sheet: Harvester File: harvester.sch VSTOR
VOUT VBAT BTN1 BTN2 BTN3 BTN4 BTN5 BTN6

File: main-board.sch Sheet: /
Id: 1/12 Title: ENGAGE Main Board

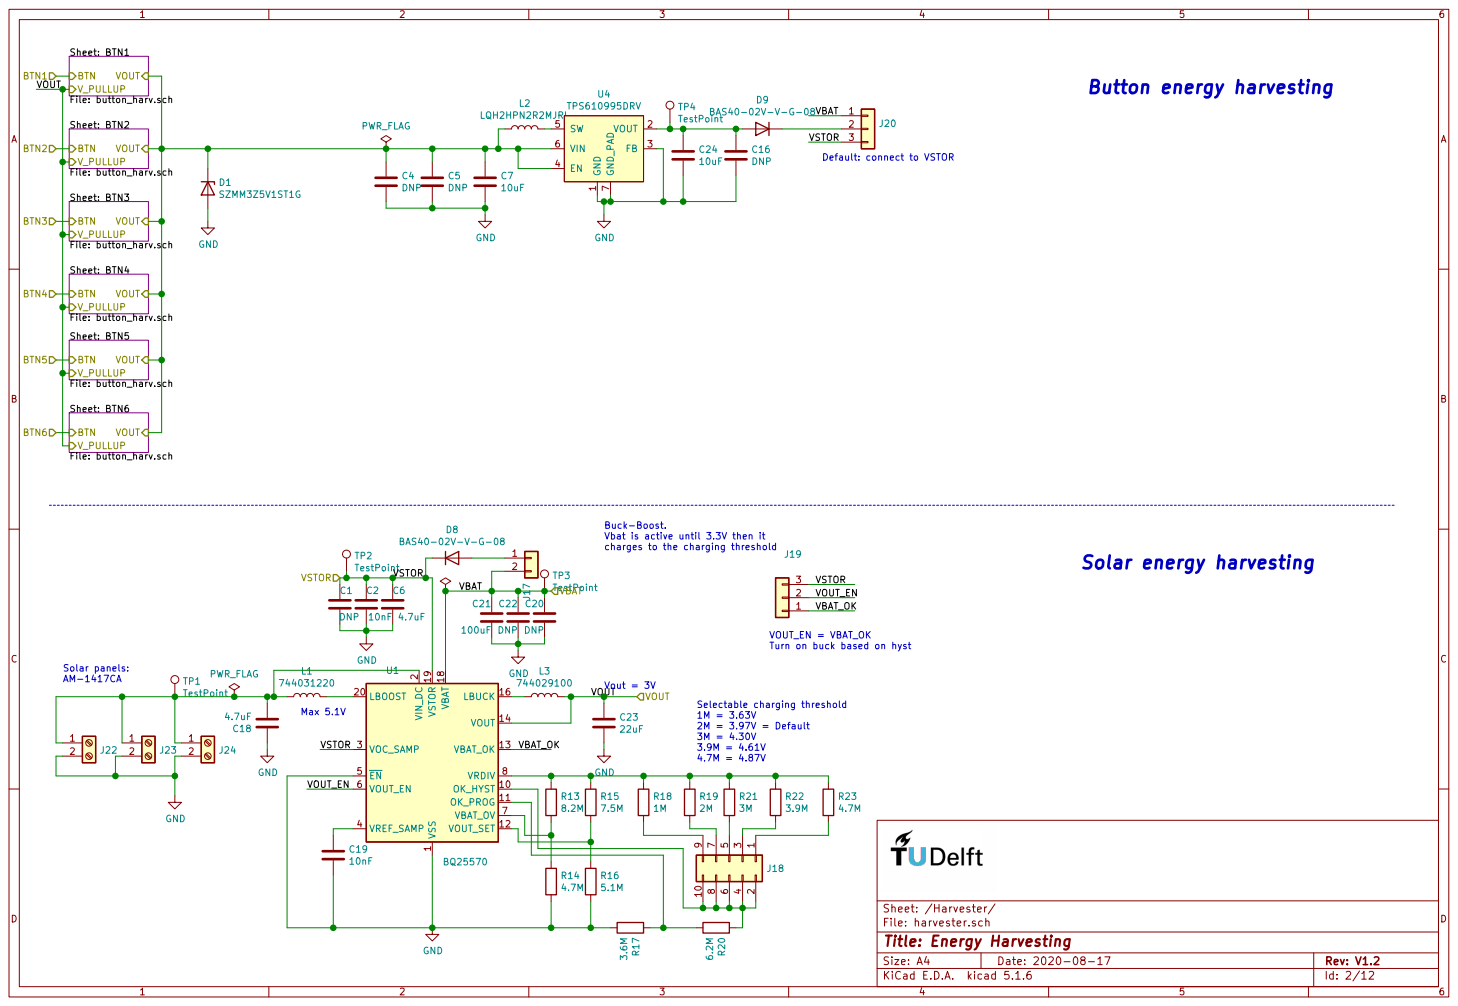
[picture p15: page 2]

1 VOUT 2 FB 3 EN 4 SW 5 VIN 6 GND_PAD

Buck-Boost. Vbat is active until 3.3V then it charges to the charging threshold

Turn on buck based on hyst

File: harvester.sch Sheet: /Harvester/
Id: 2/12 Title: Energy Harvesting

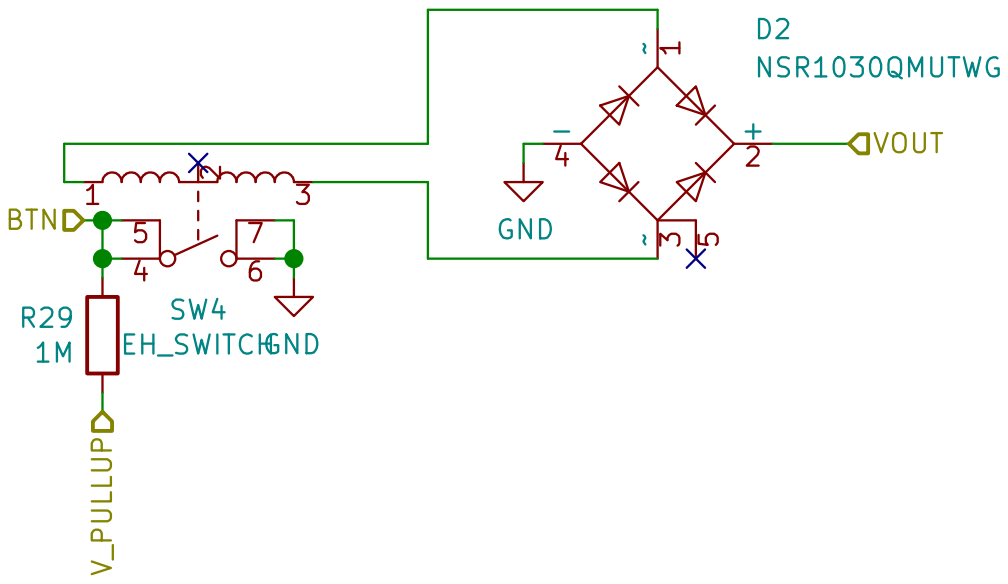
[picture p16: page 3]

File: button_harv.sch Sheet: /Harvester/BTN1/
Id: 3/12 Title: Button Energy Harvester

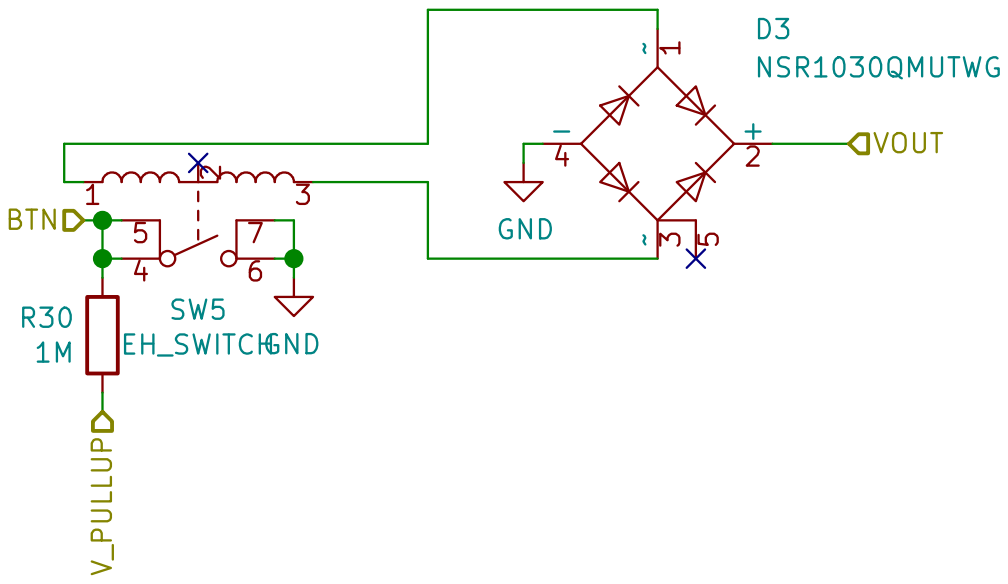
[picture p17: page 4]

File: button_harv.sch Sheet: /Harvester/BTN2/
Id: 4/12 Title: Button Energy Harvester

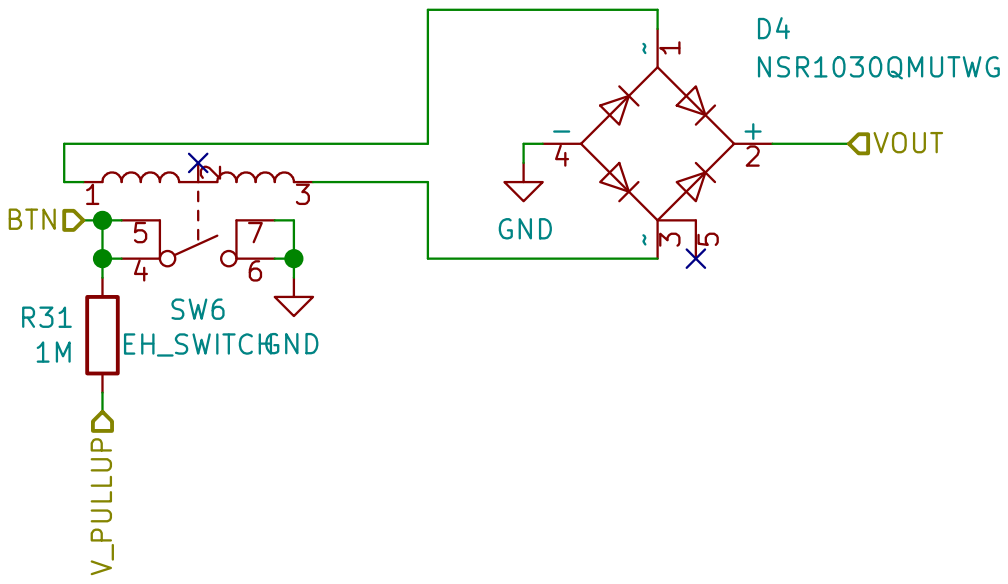
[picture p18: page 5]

File: button_harv.sch Sheet: /Harvester/BTN3/
Id: 5/12 Title: Button Energy Harvester

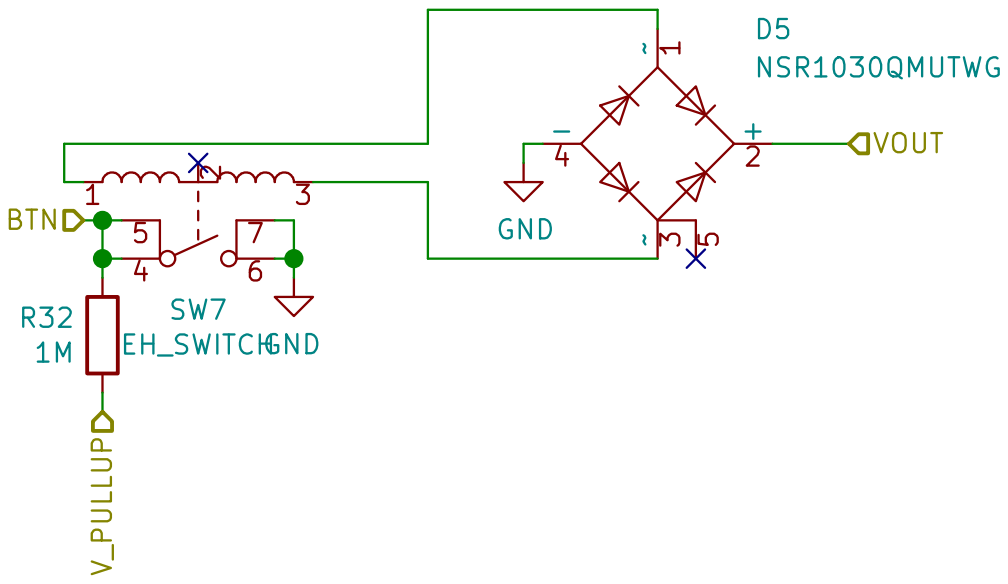
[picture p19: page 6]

File: button_harv.sch Sheet: /Harvester/BTN4/
Id: 6/12 Title: Button Energy Harvester

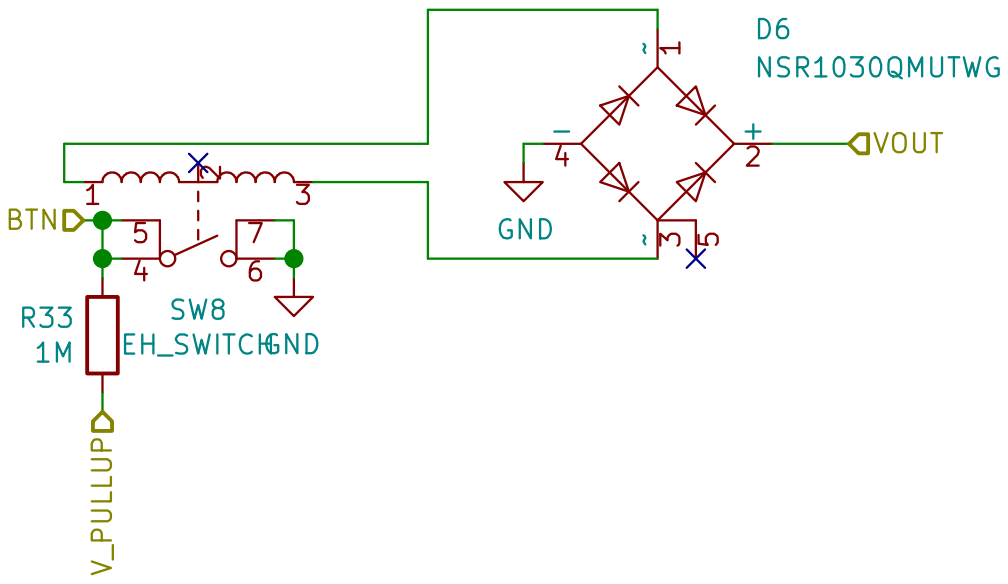
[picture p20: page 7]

File: button_harv.sch Sheet: /Harvester/BTN5/
Id: 7/12 Title: Button Energy Harvester

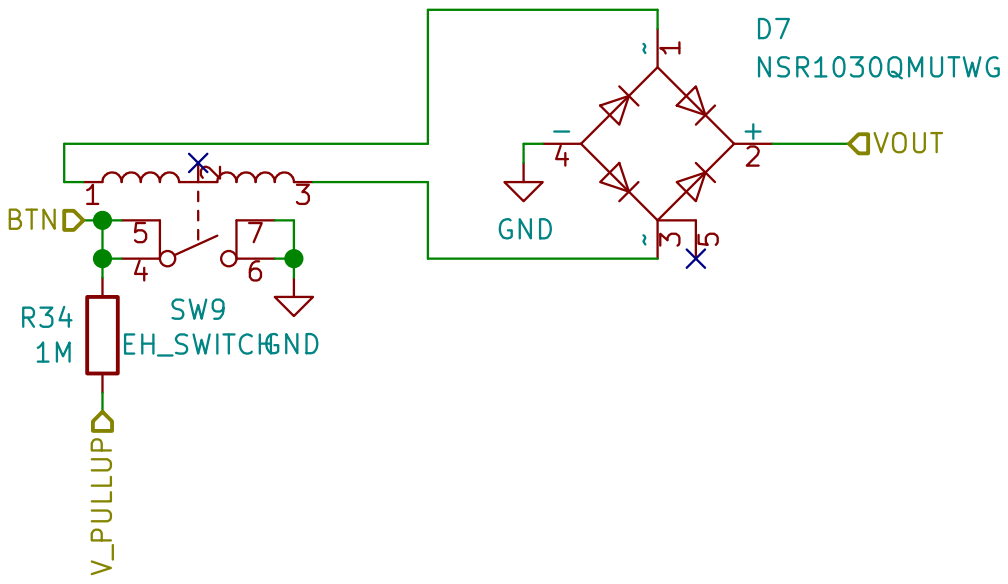
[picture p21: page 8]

File: button_harv.sch Sheet: /Harvester/BTN6/
Id: 8/12 Title: Button Energy Harvester

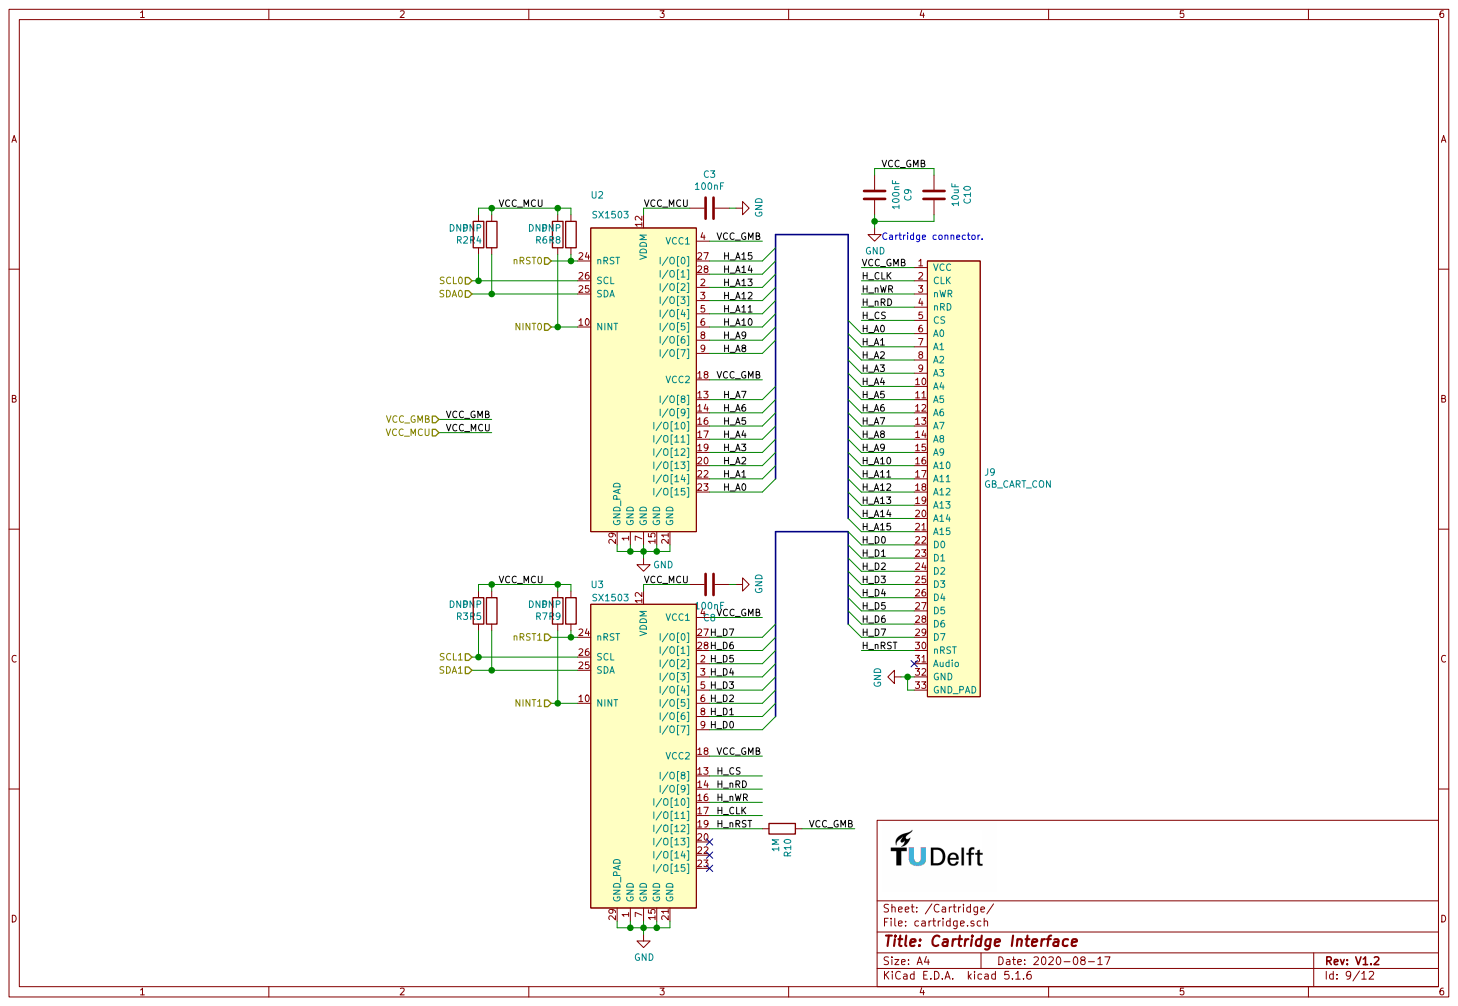
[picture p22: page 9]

File: cartridge.sch
Id: 9/12 Title: Cartridge Interface

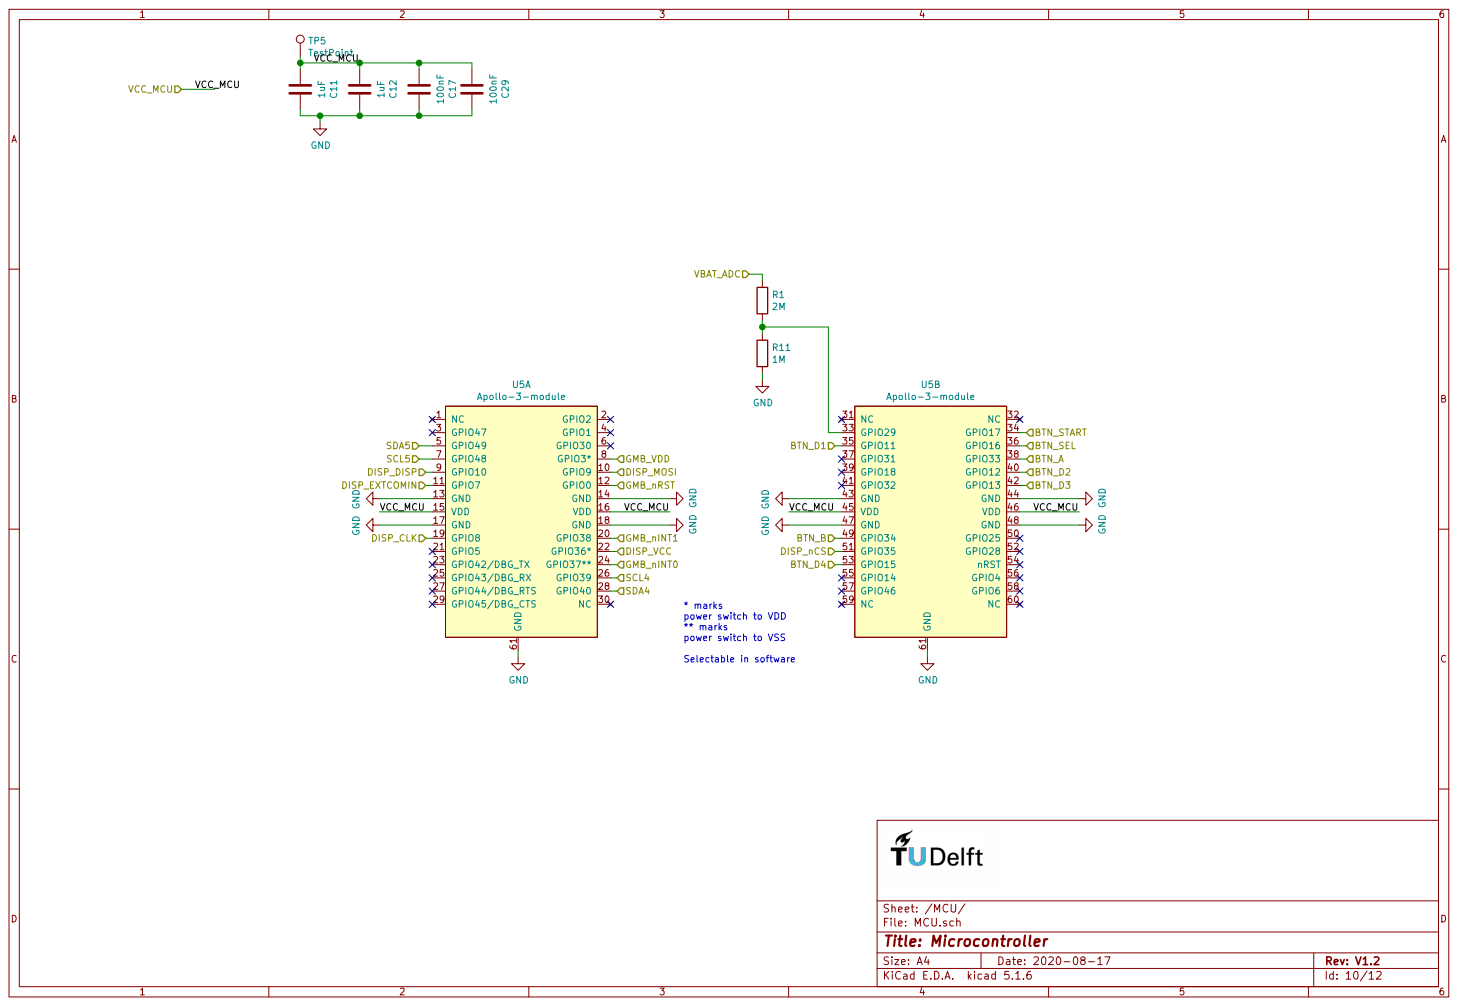
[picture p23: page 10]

* marks power switch to VDD

** marks power switch to VSS

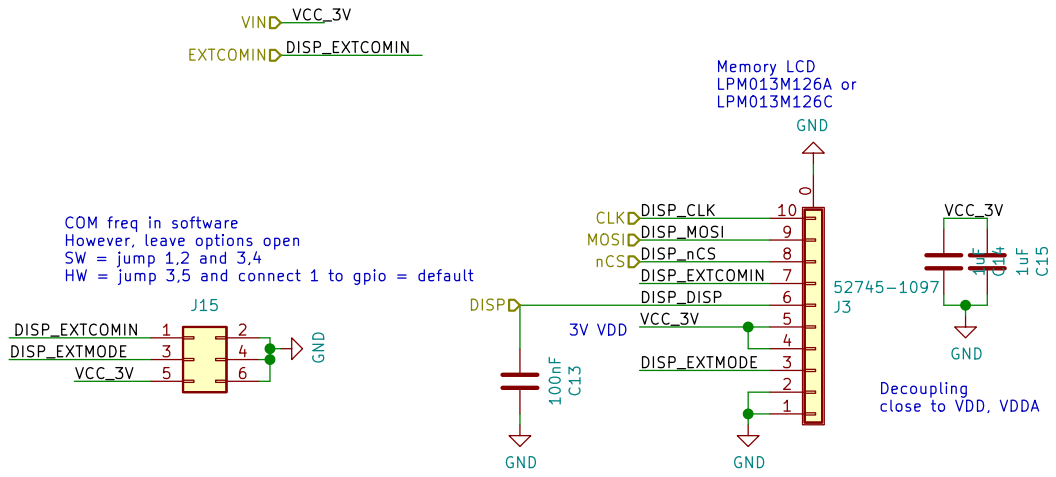
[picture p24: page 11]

Decoupling close to VDD, VDDA COM freq in software
However, leave options open
SW = jump 1,2 and 3,4
HW = jump 3,5 and connect 1 to gpio = default


2 EN 3 BP 4 FB 5 OUT 6 U7 TPS79301-EP C26

Sheet: /USB_PSU/
File: USB_PSU.sch
Id: 12/12 Title: Debugging Power Supply

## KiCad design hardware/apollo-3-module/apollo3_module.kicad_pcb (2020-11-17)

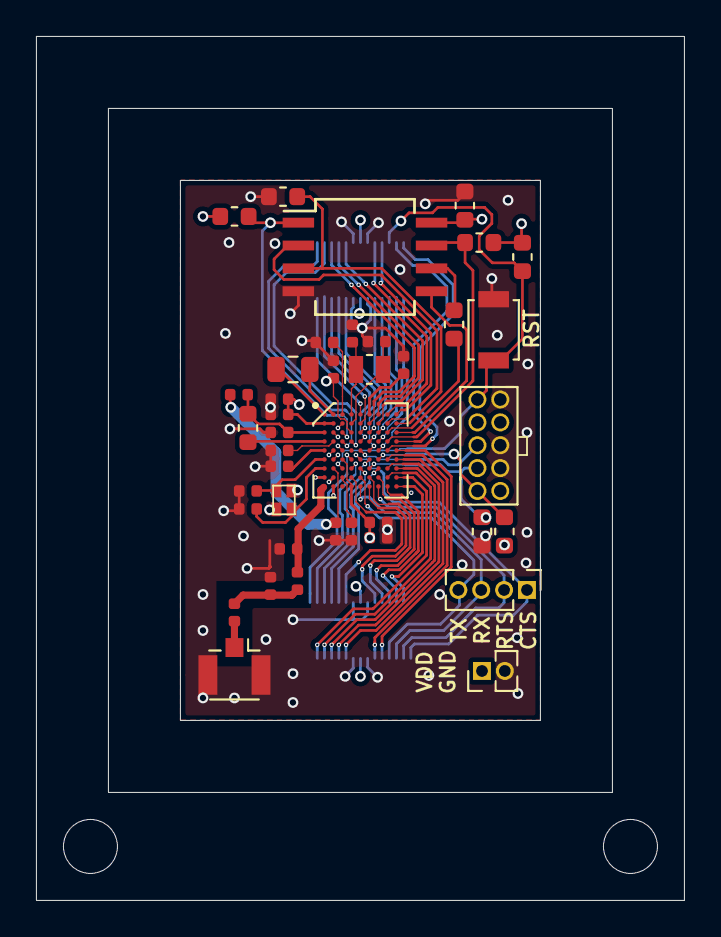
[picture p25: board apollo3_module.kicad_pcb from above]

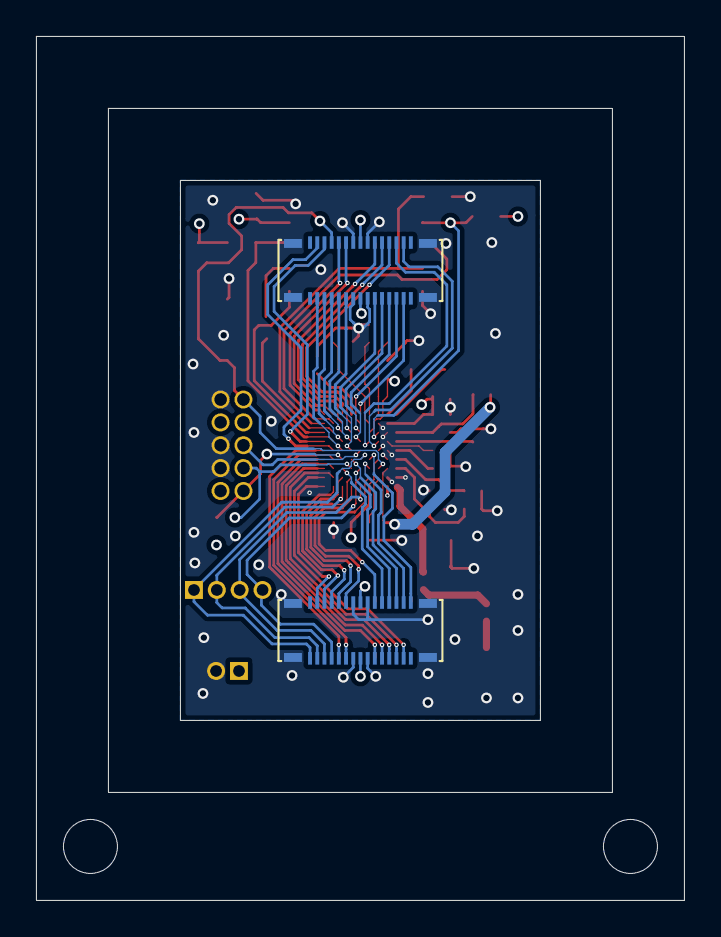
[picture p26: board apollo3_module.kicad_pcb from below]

Board: 4 copper layers, 36.0 x 48.0 mm, 44 parts (2 on the bottom side), 71 nets.

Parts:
C1, C5, C10, C11, C15: 1uF; C_0402_1005Metric
C2, C4, C13, C17, C18: DNP; C_0402_1005Metric
C3: 470nF; C_0402_1005Metric
C6: 47nF; C_0402_1005Metric
C7, C8, C9, C16: 2.2uF; C_0402_1005Metric
C12: 0.5pF; C_0402_1005Metric
C14: 4.7uF; C_0402_1005Metric
C19: 1uF; C_0603_1608Metric
H1, H2: eC_Registration; eC_Mount
J1, J2: 51338-0374
J3: Conn_01x04; PinHeader_1x04_P1.27mm_Vertical
J4: SWD_10; FTSH-105-01-F-D-K
J5: Conn_Coaxial; U.FL_Hirose_U.FL-R-SMT-1_Vertical
J6: Conn_01x02; PinHeader_1x02_P1.27mm_Vertical
L1: 2.2uH; L_0805_2012Metric
L2: 1uH; L_0603_1608Metric
L3: 2.7nH; L_0402_1005Metric
L4: 2nH; L_0402_1005Metric
R1: 0; R_0603_1608Metric
R2, R6, R7, R8: DNP; R_0603_1608Metric
R3: 0; R_0402_1005Metric
R4, R5: 10k; R_0603_1608Metric
SW1: B3U-1000P; SW_SPST_B3U-1000P
U1: APOLLO3; BGA-81_9x9_5.0x5.0mm
U2: MB85RS4MT; SO-8_5.3x6.2mm_P1.27mm
Y1: ECS-320-8-47-JTN; ECX-1247
Y2: ABS06W-32.678kHz-D-2; Crystal_SMD_MicroCrystal_CC8V-T1A-2Pin_2.0x1.2mm

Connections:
/DBG_CTS: J1.29, J3.1, U1.F5
/DBG_RTS: J1.27, J3.2, U1.J7
/DBG_RX: J1.25, J3.3, U1.J5
/DBG_TX: J1.23, J3.4, U1.H5
/FRAM_HOLD: R6.2, U1.D8, U2.7
/FRAM_WP: R7.1, U1.B9, U2.3
/G0: J1.12, U1.H4
/G1: J1.4, U1.G4
/G2: J1.2, U1.F4
/G3: J1.8, U1.G5
/G4: J2.26, U1.D9
/G5: J1.21, U1.E9
/G6: J2.28, U1.E8
/G7: J1.11, U1.F9
/G8: J1.19, U1.F8
/G9: J1.10, U1.G7
/G10: J1.9, U1.G8
/G11: J2.5, U1.B5
/G12: J2.10, U1.A7
/G13: J2.12, U1.B7
/G14: J2.25, U1.D7
/G15: J2.23, U1.C7
/G16: J2.6, U1.D4
/G17: J2.4, U1.D3
/G18: J2.9, U1.C5
/G25: J2.20, U1.A8
/G28: J2.22, U1.A9
/G29: J2.3, U1.A5
/G30: J1.6, U1.F6
/G31: J2.7, U1.D5
/G32: J2.11, U1.E6
/G33: J2.8, U1.B6
/G34: J2.19, U1.C6
/G35: J2.21, U1.D6
/G36: J1.22, U1.H6
/G37: J1.24, U1.H7
/G38: J1.20, U1.J6
/G39: J1.26, U1.J8
/G40: J1.28, U1.J9
/G46: J2.27, U1.E7
/G47: J1.3, U1.H9
/G48: J1.7, U1.G9
/G49: J1.5, U1.H8
/MSPI_CE0: R8.2, U1.C3, U2.1
/MSPI_CLK: R1.2, U2.6
/MSPI_MISO: U1.B8, U2.2
/MSPI_MOSI: U1.C9, U2.5
/SWDCK: J4.4, R4.1, U1.G6
/SWDIO: J4.2, R5.2, U1.F7
/SWO: J4.6, U1.E5
/nRST: J2.24, J4.10, R2.2, SW1.1, U1.G3
GND: C1.1, C2.2, C3.2, C4.2, C5.1, C6.2, C7.1, C8.1, C9.1, C10.1, C11.1, C12.2, C13.2, C14.2, C15.2, C16.1, C17.2, C18.1, C19.1, J1.13, J1.14, J1.17, J1.18, J1.31, J2.13, J2.14, J2.17, J2.18, J2.31, J4.3, J4.5, J4.9, J5.2, J6.2, R4.2, R7.2, SW1.2, U1.B3, U1.C2, U1.E2, U1.E3, U1.F2, U1.H1, U1.H2, U1.J2, U2.4, Y1.2, Y1.4
unnamed: C2.1, U1.G1, Y1.1
unnamed: C3.1, U1.A6
unnamed: C4.1, L3.1, U1.J1
unnamed: C6.1, U1.H3
unnamed: C7.2, U1.A3
unnamed: C8.2, U1.D2
unnamed: C9.2, U1.E1
unnamed: C12.1, L3.2, L4.1
unnamed: C13.1, U1.F1, Y1.3
unnamed: C14.1, L2.2, R3.1, U1.C1
unnamed: C15.1, R3.2, U1.G2
unnamed: C17.1, U1.A4, Y2.1
unnamed: C18.2, U1.B4, Y2.2
unnamed: J5.1, L4.2
unnamed: L1.1, U1.A1
unnamed: L1.2, U1.A2
unnamed: L2.1, U1.D1
unnamed: R1.1, U1.C8
VDD: C1.2, C5.2, C10.2, C11.2, C16.2, C19.2, J1.15, J1.16, J2.15, J2.16, J4.1, J6.1, R2.1, R5.1, R6.1, R8.1, U1.B1, U1.B2, U1.C4, U1.F3, U1.J4, U2.8

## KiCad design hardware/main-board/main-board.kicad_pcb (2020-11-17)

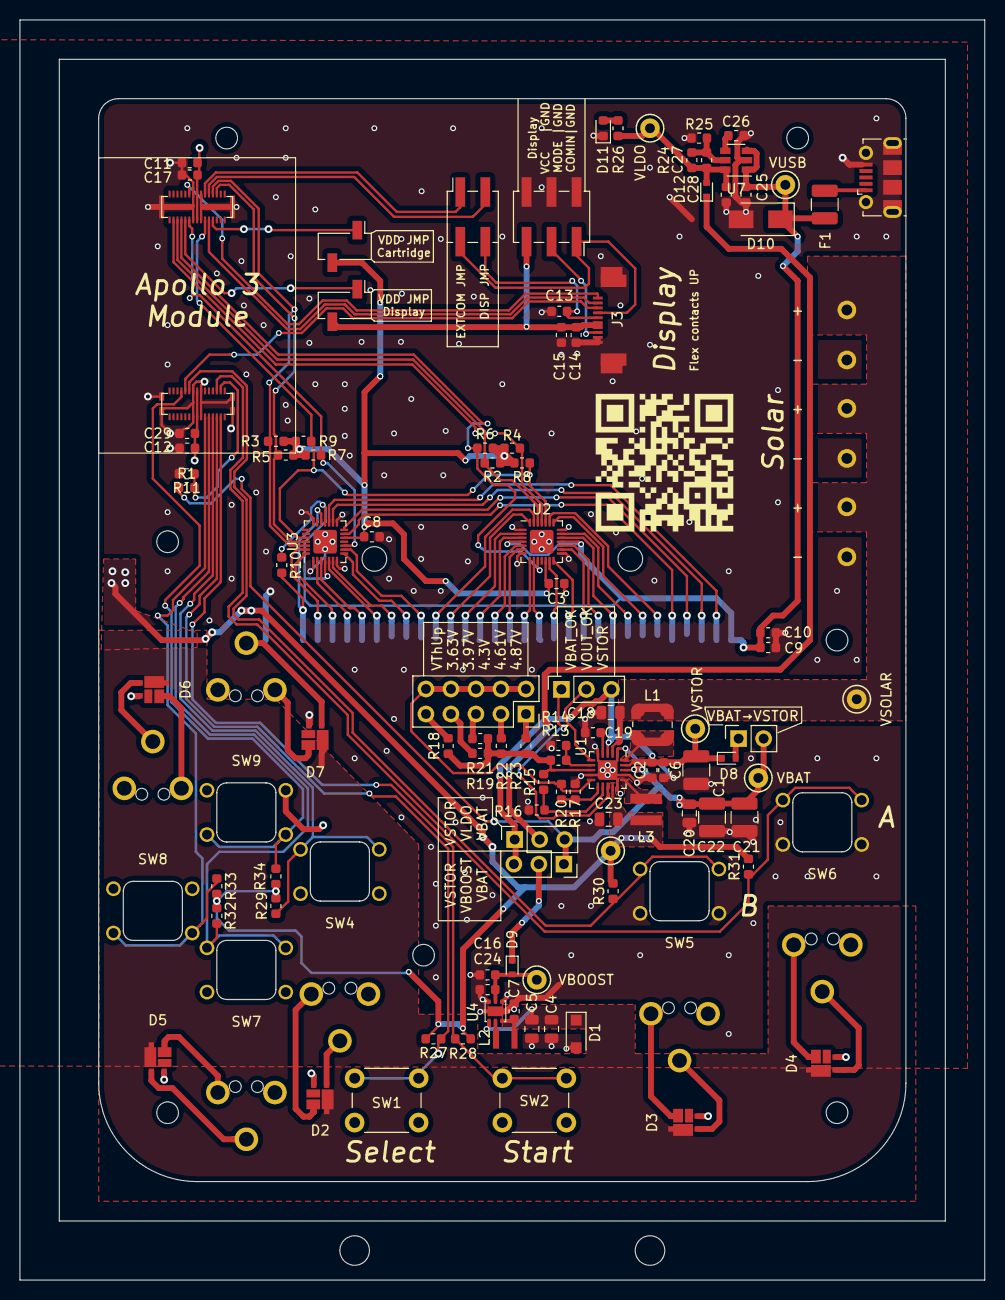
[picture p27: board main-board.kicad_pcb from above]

Board: 2 copper layers, 98.0 x 128.0 mm, 125 parts (1 on the bottom side), 101 nets.

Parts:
C1, C22: DNP; C_1210_3225Metric
C2, C19, C26: 10nF; C_0603_1608Metric
C3, C8, C9, C13, C17, C29: 100nF; C_0603_1608Metric
C4, C5, C20: DNP; C_0805_2012Metric
C6: 4.7uF; C_0603_1608Metric
C7, C10, C24, C25, C28: 10uF; C_0603_1608Metric
C11, C12, C14, C15: 1uF; C_0603_1608Metric
C16: DNP; C_0603_1608Metric
C18: 4.7uF; C_0805_2012Metric
C21: 100uF; C_1210_3225Metric
C23: 22uF; C_0805_2012Metric
C27: 15pF; C_0603_1608Metric
D1: SZMM3Z5V1ST1G; D_SOD-123F
D2, D3, D4, D5, D6, D7: NSR1030QMUTWG
D8, D9, D12: BAS40-02V-V-G-08; D_SOD-523
D10: 3SMAJ5919B-TP; D_SMA
D11: LED; LED_0603_1608Metric
F1: MF-USMF010; Fuse_1210_3225Metric
H1, H2, H3, H4, H5, H6, H7: MountingHole; MountingHole_2.2mm_M2
H8, H9: eC_Registration; eC_Mount
J1, J2: Conn_01x02; PinSocket_1x02_P2.54mm_Vertical_SMD_Pin1Left
J3: 52745-1097; FPC_10_TOP
J9: GB_CART_CON
J12: Conn_02x02_Odd_Even; PinSocket_2x02_P2.54mm_Vertical_SMD
J14, J19, J20: Conn_01x03; PinSocket_1x03_P2.54mm_Vertical
J15: Conn_02x03_Odd_Even; PinSocket_2x03_P2.54mm_Vertical_SMD
J17: Conn_01x02; PinSocket_1x02_P2.54mm_Vertical
J18: Conn_02x05_Odd_Even; PinSocket_2x05_P2.54mm_Vertical
J21: USB_B_Micro; USB_Micro-B_Molex-105017-0001
J22, J23, J24: Screw_Terminal_01x02; 282837-2
L1: 744031220; WE_3816
L2: LQH2HPN2R2MJRL; Murata_2520
L3: 744029100; WE_2813
R1, R19: 2M; R_0603_1608Metric
R2, R3, R4, R5, R6, R7, R8, R9: DNP; R_0603_1608Metric
R10, R11, R18, R27, R28, R29, R30, R31, R32, R33, R34: 1M; R_0603_1608Metric
R13: 8.2M; R_0603_1608Metric
R14, R23: 4.7M; R_0603_1608Metric
R15: 7.5M; R_0603_1608Metric
R16: 5.1M; R_0603_1608Metric
R17: 3.6M; R_0603_1608Metric
R20: 6.2M; R_0603_1608Metric
R21: 3M; R_0603_1608Metric
R22: 3.9M; R_0603_1608Metric
R24: 82k; R_0603_1608Metric
R25: 30.1k; R_0603_1608Metric
R26: 560; R_0603_1608Metric
S1: TUD_SSL_QR; TUDSSL
S2: TUD_LOGO; DELFT_LOGO2
SW1, SW2: SW_Push; SW_PUSH_6mm
SW4, SW5, SW6, SW7, SW8, SW9: EH_SWITCH
TP1, TP2, TP3, TP4, TP5, TP6, TP7: TestPoint; TestPoint_Keystone_5000-5004_Miniature
U1: BQ25570; QFN-20-1EP_3.5x3.5mm_P0.5mm_EP2x2mm
U2, U3: SX1503; QFN-28-1EP_4x4mm_P0.4mm_EP2.4x2.4mm
U4: TPS610995DRV; Texas_WSON_6
U5: Apollo-3-module; Apollo-3-Module
U7: TPS79301-EP; SOT-23-6

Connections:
/BTN_SEL: R28.1, SW2.2, U5.34
/BTN_START: R27.1, SW1.2, U5.36
/Cartridge/H_A0: J9.6, U2.23
/Cartridge/H_A1: J9.7, U2.22
/Cartridge/H_A2: J9.8, U2.20
/Cartridge/H_A3: J9.9, U2.19
/Cartridge/H_A4: J9.10, U2.17
/Cartridge/H_A5: J9.11, U2.16
/Cartridge/H_A6: J9.12, U2.14
/Cartridge/H_A7: J9.13, U2.13
/Cartridge/H_A8: J9.14, U2.9
/Cartridge/H_A9: J9.15, U2.8
/Cartridge/H_A10: J9.16, U2.6
/Cartridge/H_A11: J9.17, U2.5
/Cartridge/H_A12: J9.18, U2.3
/Cartridge/H_A13: J9.19, U2.2
/Cartridge/H_A14: J9.20, U2.28
/Cartridge/H_A15: J9.21, U2.27
/Cartridge/H_CLK: J9.2, U3.17
/Cartridge/H_CS: J9.5, U3.13
/Cartridge/H_D0: J9.22, U3.9
/Cartridge/H_D1: J9.23, U3.8
/Cartridge/H_D2: J9.24, U3.6
/Cartridge/H_D3: J9.25, U3.5
/Cartridge/H_D4: J9.26, U3.3
/Cartridge/H_D5: J9.27, U3.2
/Cartridge/H_D6: J9.28, U3.28
/Cartridge/H_D7: J9.29, U3.27
/Cartridge/H_nRD: J9.4, U3.14
/Cartridge/H_nRST: J9.30, R10.2, U3.19
/Cartridge/H_nWR: J9.3, U3.16
/Cartridge/SCL0: R2.1, U2.26, U5.26
/Cartridge/SCL1: R3.1, U3.26, U5.7
/Cartridge/SDA0: R4.1, U2.25, U5.28
/Cartridge/SDA1: R5.1, U3.25, U5.5
/Cartridge/VCC_MCU: C3.1, C8.2, J2.2, R2.2, R3.2, R4.2, R5.2, R6.2, R7.2, R8.2, R9.2, U2.12, U3.12
/Display/CLK: J3.10, U5.19
/Display/DISP: C13.1, J3.6, J12.4
/Display/DISP_EXTMODE: J3.3, J15.3
/Display/EXTCOMIN: J3.7, J12.2, J15.1
/Display/VIN: C14.1, C15.1, J1.2, J3.4, J3.5, J15.5
/Harvester/BTN1: R29.1, SW4.4, SW4.5, U5.38
/Harvester/BTN1/VOUT: C4.1, C5.1, C7.1, D1.1, D2.2, D3.2, D4.2, D5.2, D6.2, D7.2, L2.1, U4.4, U4.6
/Harvester/BTN2: R30.1, SW5.4, SW5.5, U5.49
/Harvester/BTN3: R31.1, SW6.4, SW6.5, U5.35
/Harvester/BTN4: R32.1, SW7.4, SW7.5, U5.40
/Harvester/BTN5: R33.1, SW8.4, SW8.5, U5.42
/Harvester/BTN6: R34.1, SW9.4, SW9.5, U5.53
/Harvester/VBAT: C20.2, C21.2, C22.2, J14.3, J17.2, J20.1, R1.1, TP3.1, U1.18
/Harvester/VBAT_OK: J19.1, U1.13
/Harvester/VOUT_EN: J19.2, U1.6
/Harvester/VSTOR: C1.2, C2.2, C6.2, D8.1, J14.1, J19.3, J20.3, TP2.1, U1.3, U1.19
/MCU/DISP_DISP: J12.3, U5.9
/MCU/DISP_EXTCOMIN: J12.1, U5.11
/MCU/DISP_MOSI: J3.9, U5.10
/MCU/DISP_VCC: J1.1, U5.22
/MCU/DISP_nCS: J3.8, U5.51
/MCU/GMB_VDD: J2.1, U5.8
/MCU/GMB_nINT0: R6.1, U2.10, U5.24
/MCU/GMB_nINT1: R7.1, U3.10, U5.20
/MCU/GMB_nRST: R8.1, R9.1, U2.24, U3.24, U5.12
/USB_VOUT: D12.1, J14.2
/VCC_3V: C11.1, C12.1, C17.1, C23.1, C29.1, L3.2, R27.2, R28.2, R29.2, R30.2, R31.2, R32.2, R33.2, R34.2, TP5.1, U1.14, U5.15, U5.16, U5.45, U5.46
/VCC_5V: C9.1, C10.1, C25.1, D10.1, F1.2, J9.1, R10.1, TP6.1, U2.4, U2.18, U3.4, U3.18, U7.1, U7.3
GND: C1.1, C2.1, C3.2, C4.2, C5.2, C6.1, C7.2, C8.1, C9.2, C10.2, C11.2, C12.2, C13.2, C14.2, C15.2, C16.2, C17.2, C18.1, C19.2, C20.1, C21.1, C22.1, C23.2, C24.2, C25.2, C26.2, C28.2, C29.2, D1.2, D2.4, D3.4, D4.4, D5.4, D6.4, D7.4, D10.2, D11.1, J3.0, J3.1, J3.2, J9.32, J9.33, J15.2, J15.4, J15.6, J21.5, J21.6, J22.2, J23.2, J24.2, R11.2, R14.2, R16.2, R17.2, R25.2, SW1.1, SW2.1, SW4.6, SW4.7, SW5.6, SW5.7, SW6.6, SW6.7, SW7.6, SW7.7, SW8.6, SW8.7, SW9.6, SW9.7, U1.1, U1.5, U1.9, U1.15, U1.17, U1.21, U2.1, U2.7, U2.15, U2.21, U2.29, U3.1, U3.7, U3.15, U3.21, U3.29, U4.1, U4.3, U4.7, U5.13, U5.14, U5.17, U5.18, U5.43, U5.44, U5.47, U5.48, U5.61, U7.2
unnamed: C16.1, C24.1, D9.2, TP4.1, U4.2
unnamed: C18.2, J22.1, J23.1, J24.1, L1.1, TP1.1, U1.2
unnamed: C19.1, U1.4
unnamed: C26.1, U7.4
unnamed: C27.1, C28.1, D12.2, R24.1, R26.1, TP7.1, U7.6
unnamed: C27.2, R24.2, R25.1, U7.5
unnamed: D2.1, SW4.1
unnamed: D2.3, SW4.3
unnamed: D3.1, SW5.1
unnamed: D3.3, SW5.3
unnamed: D4.1, SW6.1
unnamed: D4.3, SW6.3
unnamed: D5.1, SW7.1
unnamed: D5.3, SW7.3
unnamed: D6.1, SW8.1
unnamed: D6.3, SW8.3
unnamed: D7.1, SW9.1
unnamed: D7.3, SW9.3
unnamed: D8.2, J17.1
unnamed: D9.1, J20.2
unnamed: D11.2, R26.2
unnamed: F1.1, J21.1
unnamed: J18.1, R23.2
unnamed: J18.3, R22.2
unnamed: J18.5, R21.2
unnamed: J18.7, R19.2
unnamed: J18.9, R18.2
unnamed: J18.2, J18.4, J18.6, J18.8, J18.10, R20.1, U1.10
unnamed: L1.2, U1.20
unnamed: L2.2, U4.5
unnamed: L3.1, U1.16
unnamed: R1.2, R11.1, U5.33
unnamed: R13.1, R15.1, R18.1, R19.1, R21.1, R22.1, R23.1, U1.8
unnamed: R13.2, R14.1, U1.7
unnamed: R15.2, R16.1, U1.12
unnamed: R17.1, R20.2, U1.11

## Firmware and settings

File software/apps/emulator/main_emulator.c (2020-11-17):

/*
 * emulator.c
 *
 *  Created on: Jan 23, 2020
 *      Author: TU Delft Sustainable Systems Laboratory
 *     License: MIT License
 */

#include "am_mcu_apollo.h"
#include "am_util.h"
#include "checkpoint.h"
#include "checkpoint_memtracker.h"
#include "emulator.h"
#include "emulator_settings.h"
#include "fram.h"
#include "mpatch.h"
#include "mspi.h"
#include "platform.h"
#include "reader.h"
#include "z80_ub.h"

#define MSPI_TEST_MODULE 0

#if defined(AM_PART_APOLLO3)
#define MSPI_XIP_BASE_ADDRESS 0x04000000
#define MSPI_XIPMM_BASE_ADDRESS 0x51000000
#define MSPI_XIPMM_SIZE 0x100000
#elif defined(AM_PART_APOLLO3P)
#define MSPI_XIP_BASE_ADDRESS 0x02000000
#endif

CHECKPOINT_EXCLUDE_BSS uint32_t DMATCBBuffer_FRAM[2560];

const am_hal_mspi_dev_config_t MSPI_Flash_Serial_CE0_MSPIConfig = {
    .eSpiMode = AM_HAL_MSPI_SPI_MODE_0,
    .eClockFreq = AM_HAL_MSPI_CLK_24MHZ,
    .ui8TurnAround = 0,
    .eAddrCfg = AM_HAL_MSPI_ADDR_3_BYTE,
    .eInstrCfg = AM_HAL_MSPI_INSTR_1_BYTE,
    .eDeviceConfig = AM_HAL_MSPI_FLASH_SERIAL_CE0,
    .bSeparateIO = true,
    .bSendInstr = true,
    .bSendAddr = true,
    .bTurnaround = true,
    .ui8ReadInstr = FRAM_READ_MEM_CODE,
    .ui8WriteInstr = FRAM_WRITE_MEM_CODE,
    .ui32TCBSize = (sizeof(DMATCBBuffer_FRAM) / sizeof(uint32_t)),
    .pTCB = DMATCBBuffer_FRAM,
    .scramblingStartAddr = 0,
    .scramblingEndAddr = 0,
};

#ifdef CHECKPOINT
extern void startup_clear_data(void);
extern void startup_clear_bss(void);
#endif

int init(void) {
  uint32_t ui32Status;
  void* pHandle = NULL;

  //
  // Set the clock frequency.
  //
  am_hal_clkgen_control(AM_HAL_CLKGEN_CONTROL_SYSCLK_MAX, 0);

  //
  // Set the default cache configuration
  //
  am_hal_cachectrl_config(&am_hal_cachectrl_defaults);
  am_hal_cachectrl_enable();
  // am_hal_cachectrl_disable();
  //
  // Initialize for low power in the power control block
  //
  am_hal_pwrctrl_low_power_init();

  //
  // Disable the RTC.
  //
  am_hal_rtc_osc_disable();

  // uncomment for debug output
  //  am_hal_tpiu_config_t TPIUcfg;
  //  //
  //  // Set the global print interface.
  //  //
  //
  //  //
  //  // Enable the ITM interface and the SWO pin.
  //  //
  //  am_hal_itm_enable();
  //
  //  //
  //  // Enable the ITM and TPIU
  //  // Set the BAUD clock for 1M
  //  //
  //  TPIUcfg.ui32SetItmBaud = AM_HAL_TPIU_BAUD_1M;
  //  am_hal_tpiu_enable(&TPIUcfg);
  //  am_hal_gpio_pincfg_t pinCfg = {
  //      .uFuncSel            = AM_HAL_PIN_41_SWO,
  //      .eDriveStrength      = AM_HAL_GPIO_PIN_DRIVESTRENGTH_2MA
  //  };
  //  am_hal_gpio_pinconfig(SWD_PIN, pinCfg);
  //
  //  //
  //  // Attach the ITM to the STDIO driver.
  //  //
  //  am_util_stdio_printf_init(am_hal_itm_print);
  //
  //  //
  //  // Print the banner.
  //  //
  //  am_util_stdio_terminal_clear();
  // end of debug output

  am_hal_burst_avail_e eBurstModeAvailable;
  am_hal_burst_mode_initialize(&eBurstModeAvailable);

  am_hal_burst_mode_e eBurstMode;
  if (eBurstModeAvailable == AM_HAL_BURST_AVAIL) {
    am_hal_burst_mode_enable(&eBurstMode);  // operate at 96MHz
    am_util_stdio_printf("Enabled burst operation\n");
  } else {
    am_util_stdio_printf("Burst not availible\n");
  }

  //
  // Configure the MSPI and Flash Device.
  //
  ui32Status = am_devices_mspi_psram_init(
      MSPI_TEST_MODULE,
      (am_hal_mspi_dev_config_t*)&MSPI_Flash_Serial_CE0_MSPIConfig, &pHandle);
  if (AM_DEVICES_MSPI_PSRAM_STATUS_SUCCESS != ui32Status) {
    am_util_stdio_printf(
        "Failed to configure the MSPI and Flash Device correctly!\n");
    return -1;
  }

  //
  // Set up for XIP operation.
  //
  ui32Status = am_devices_mspi_psram_enable_xip();
  if (AM_DEVICES_MSPI_PSRAM_STATUS_SUCCESS != ui32Status) {
    am_util_stdio_printf("Failed to enable XIP mode in the MSPI!\n");
    return -2;
  }

  return 0;
}

int deinit(void) {
  uint32_t ui32Status;

  //
  // Shutdown XIP operation.
  //
  am_util_stdio_printf("Disabling the MSPI and External Flash from XIP mode\n");
  ui32Status = am_devices_mspi_psram_disable_xip();
  if (AM_DEVICES_MSPI_PSRAM_STATUS_SUCCESS != ui32Status) {
    am_util_stdio_printf("Failed to disable XIP mode in the MSPI!\n");
    return -2;
  }

  //
  // Clean up the MSPI before exit.
  //
  ui32Status = am_devices_mspi_psram_deinit(
      MSPI_TEST_MODULE,
      (am_hal_mspi_dev_config_t*)&MSPI_Flash_Serial_CE0_MSPIConfig);
  if (AM_DEVICES_MSPI_PSRAM_STATUS_SUCCESS != ui32Status) {
    am_util_stdio_printf("Failed to shutdown the MSPI and Flash Device!\n");
    return -1;
  }

  return 0;
}

int main(void) {
  init();

  am_util_stdio_printf("Emulator Checkpoint Test\n\n");

#ifdef CHECKPOINT
  /* Restore overwrite (i.e. restart the game) */
  am_hal_gpio_pinconfig(BUTTON_START, g_AM_HAL_GPIO_INPUT);
  am_hal_gpio_pinconfig(BUTTON_SELECT, g_AM_HAL_GPIO_INPUT);

  if (((am_hal_gpio_input_read(BUTTON_START) == 0) &&
       (am_hal_gpio_input_read(BUTTON_SELECT) == 0)) ||
      ((am_hal_gpio_input_read(BUTTON_START) == 0) &&
       (am_hal_gpio_input_read(BUTTON_A) == 0))) {
    // Force reset
    am_util_stdio_printf("Restart execution\n\n");
    checkpoint_restore_invalidate();
  }

  if (!checkpoint_restore_available()) {
    // First boot
    // Init the .bss and .data (no-restore parts already init in startup)

    // Init the remaining .data
    startup_clear_data();

    // Zero the remaining .bss
    startup_clear_bss();

    if (checkSavedCartridge((uint8_t*)GameRomStart)) {
      emulatorSetRomSize(cartridgeGetSizeBytes());
    } else {
      emulatorSetRomSize(0);
    }
  }

  if ((am_hal_gpio_input_read(BUTTON_START) == 0) &&
      (am_hal_gpio_input_read(BUTTON_A) == 0)) {
    // Read cartridge
    am_util_stdio_printf(
        "Reading cartridge to memory, takes up to 1-10 mins! \n\n");
    cartridgeConfig();

    cartridgeReadInfo();
    cartridgeReadRom();
    emulatorSetRomSize(cartridgeGetSizeBytes());
  }

  am_util_stdio_printf("Checkpoint setup (always)\n");
  checkpoint_setup();

  am_util_stdio_printf("Attempting restore\n\n");
  checkpoint_restore();

  am_util_stdio_printf("No restore available\n\n");

  am_util_stdio_printf("One-time checkpoint setup\n");
  checkpoint_onetime_setup();

  emulatorConfigIO();
  emulatorSetup();

  // First time setup (has to be after the emulatorInit()
  setup_memtracker();

  // Add the z80 memory as a "starting state"
  checkpoint_memtracker_default();

  am_util_stdio_printf("After init checkpoint\n\n");
  checkpoint();

  checkpoint_restore_set_availible();

  am_util_stdio_printf("Start emulator\n\n");
  emulatorRun();

#else
  emulatorSetup();
  emulatorRun();
#endif
}

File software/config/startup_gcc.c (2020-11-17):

//*****************************************************************************
//
//! @file startup_gcc.c
//!
//! @brief Definitions for interrupt handlers, the vector table, and the stack.
//
//*****************************************************************************

//*****************************************************************************
//
// Copyright (c) 2019, Ambiq Micro
// All rights reserved.
//
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
// 2. Redistributions in binary form must reproduce the above copyright
// notice, this list of conditions and the following disclaimer in the
// documentation and/or other materials provided with the distribution.
//
// 3. Neither the name of the copyright holder nor the names of its
// contributors may be used to endorse or promote products derived from this
// software without specific prior written permission.
//
// Third party software included in this distribution is subject to the
// additional license terms as defined in the /docs/licenses directory.
//
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
// This is part of revision 2.3.2 of the AmbiqSuite Development Package.
//
//*****************************************************************************

#include <stdint.h>
#include "emulator_settings.h"

//*****************************************************************************
//
// Forward declaration of interrupt handlers.
//
//*****************************************************************************
extern void Reset_Handler(void)       __attribute ((naked));
extern void NMI_Handler(void)         __attribute ((weak));
extern void HardFault_Handler(void)   __attribute ((weak));
extern void MemManage_Handler(void)   __attribute ((weak, alias ("HardFault_Handler")));
extern void BusFault_Handler(void)    __attribute ((weak, alias ("HardFault_Handler")));
extern void UsageFault_Handler(void)  __attribute ((weak, alias ("HardFault_Handler")));
extern void SecureFault_Handler(void) __attribute ((weak));
extern void SVC_Handler(void)         __attribute ((weak, alias ("am_default_isr")));
extern void DebugMon_Handler(void)    __attribute ((weak, alias ("am_default_isr")));
extern void PendSV_Handler(void)      __attribute ((weak, alias ("am_default_isr")));
extern void SysTick_Handler(void)     __attribute ((weak, alias ("am_default_isr")));

extern void am_brownout_isr(void)     __attribute ((weak, alias ("am_default_isr")));
extern void am_watchdog_isr(void)     __attribute ((weak, alias ("am_default_isr")));
extern void am_rtc_isr(void)          __attribute ((weak, alias ("am_default_isr")));
extern void am_vcomp_isr(void)        __attribute ((weak, alias ("am_default_isr")));
extern void am_ioslave_ios_isr(void)  __attribute ((weak, alias ("am_default_isr")));
extern void am_ioslave_acc_isr(void)  __attribute ((weak, alias ("am_default_isr")));
extern void am_iomaster0_isr(void)    __attribute ((weak, alias ("am_default_isr")));
extern void am_iomaster1_isr(void)    __attribute ((weak, alias ("am_default_isr")));
extern void am_iomaster2_isr(void)    __attribute ((weak, alias ("am_default_isr")));
extern void am_iomaster3_isr(void)    __attribute ((weak, alias ("am_default_isr")));
extern void am_iomaster4_isr(void)    __attribute ((weak, alias ("am_default_isr")));
extern void am_iomaster5_isr(void)    __attribute ((weak, alias ("am_default_isr")));
extern void am_ble_isr(void)          __attribute ((weak, alias ("am_default_isr")));
extern void am_gpio_isr(void)         __attribute ((weak, alias ("am_default_isr")));
extern void am_ctimer_isr(void)       __attribute ((weak, alias ("am_default_isr")));
extern void am_uart_isr(void)         __attribute ((weak, alias ("am_default_isr")));
extern void am_uart1_isr(void)        __attribute ((weak, alias ("am_default_isr")));
extern void am_scard_isr(void)        __attribute ((weak, alias ("am_default_isr")));
extern void am_adc_isr(void)          __attribute ((weak, alias ("am_default_isr")));
extern void am_pdm0_isr(void)         __attribute ((weak, alias ("am_default_isr")));
extern void am_mspi0_isr(void)        __attribute ((weak, alias ("am_default_isr")));
extern void am_software0_isr(void)    __attribute ((weak, alias ("am_default_isr")));
extern void am_stimer_isr(void)       __attribute ((weak, alias ("am_default_isr")));
extern void am_stimer_cmpr0_isr(void) __attribute ((weak, alias ("am_default_isr")));
extern void am_stimer_cmpr1_isr(void) __attribute ((weak, alias ("am_default_isr")));
extern void am_stimer_cmpr2_isr(void) __attribute ((weak, alias ("am_default_isr")));
extern void am_stimer_cmpr3_isr(void) __attribute ((weak, alias ("am_default_isr")));
extern void am_stimer_cmpr4_isr(void) __attribute ((weak, alias ("am_default_isr")));
extern void am_stimer_cmpr5_isr(void) __attribute ((weak, alias ("am_default_isr")));
extern void am_stimer_cmpr6_isr(void) __attribute ((weak, alias ("am_default_isr")));
extern void am_stimer_cmpr7_isr(void) __attribute ((weak, alias ("am_default_isr")));
extern void am_clkgen_isr(void)       __attribute ((weak, alias ("am_default_isr")));

extern void am_default_isr(void)      __attribute ((weak));

//*****************************************************************************
//
// The entry point for the application.
//
//*****************************************************************************
extern int main(void);

//*****************************************************************************
//
// Reserve space for the system stack.
//
//*****************************************************************************
__attribute__ ((section(".stack")))
static uint32_t g_pui32Stack[0xac0];
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

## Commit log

2020-11-17 initial code version
    [CPPLINT.cfg, Display.sch, ENGAGE-Bottom.stl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]
2020-12-25 Improve README
    Cleaned up a few typos and clarified wording in a couple places.
